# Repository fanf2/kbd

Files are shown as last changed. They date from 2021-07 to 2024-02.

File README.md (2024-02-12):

Tony Finch's keyboard projects
==============================

This repository is where I keep my work on custom mechanical
keyboards.

[HHKBeeb](./hhkbeeb/)
---------

The first keyboard I built is a tribute to the BBC Micro made in the
run-up to its 40th anniversary in 2021.

It uses a [Yiancar HS60](https://yiancar-designs.com/portfolio/337/)
PCB and a generic HHKB case, and keycaps designed by me and printed by
WASD.

The project directory [hhkbeeb](./hhkbeeb/) also contains designs for
an acrylic sandwich case that I never made.

> The default branch in this repository is jokingly called `model-b`
> because git's default branch used to be `master`, and both are kinds
> of BBC Micro.

[Keybird69](./keybird69/)
-----------

In 2023 I designed a 65% keyboard with a "unix69" layout. It uses a
Waveshare RP2040-Tiny controller on a PCB designed by me. The case is
a sandwich of FR-4 and LEGO.

I have assembled three versions of Keybird69:

 1. with Cherry MX Clear switches and Signature Plastics DSS
    "Dolch" keycaps

 2. Cherry MX Clear switches again but with the springs
    lubericated to eliminate their pinging; and with
    [matt3o](https://matt3o.com)'s GMK MTNU Susu keycaps.

 3. Gateron CAP milky brown switches with JTK HSA Hyperfuse keycaps

[Keybird42](./keybird42/)
-----------

My late 2023 / early 2024 work in progress is series of 77% boards:

  - bigger than 75%
  - fewer keys than 80%
  - more symmetrical

They are called keybird42:

  * 42 cm wide PCB
  * 21 keys wide (42 / 2)
  * 84 keys total (42 * 2)

The first version will have a layered acrylic case; there may be others.

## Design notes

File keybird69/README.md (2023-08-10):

Keybird69
=========

This subdirectory contains the notes and designs for Keybird69,
a 65% (69 key) keyboard with a [unix69][] layout and a case made from
FR-4 and LEGO.

[unix69]: https://dotat.at/@/2023-08-04-unix69.html

For blog posts about this keyboard, see

  * <https://dotat.at/@/2023-08-04-keybird.html>

And the followup posts that go into some of the details.

The firmware can be found at:

  * https://github.com/fanf2/qmk_firmware/tree/fanf/keyboards/handwired/fanf/keybird69

Here you can find:

  * `Cargo.toml`
  * `src`
      * some Rust code for generating parts of the QMK configuration,
        and for cross-checking the key matrix design

  * `lego.md`
  * `pcba.md`
      * notes and calculations for the case dimensions

  * `keycaps.md`
      * window-shopping for keycaps for a [unix69][] layout

  * `kicad`
      * schematic and layout for the PCB

  * `ltbs-base`
  * `ltbs-top`
      * kicad designs for the base plate and key switch mounting plate

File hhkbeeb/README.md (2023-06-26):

A keyboard like the BBC Micro, made from modern parts
=====================================================

It's the 40th anniversary of the BBC Micro later this year. I am
trying to make a keyboard in a similar style, made from modern parts.

The Beeb's keyboard was what is now called a mechanical keyboard.
There's a very lively community of mechanical keyboard makers and
customizers, who have made it fairly easy to get a long way with
off-the-shelf parts.

If you would like to make a similar keyboard, please feel free to use
this work as you wish - see the [LICENSE](LICENSE.md) for details.

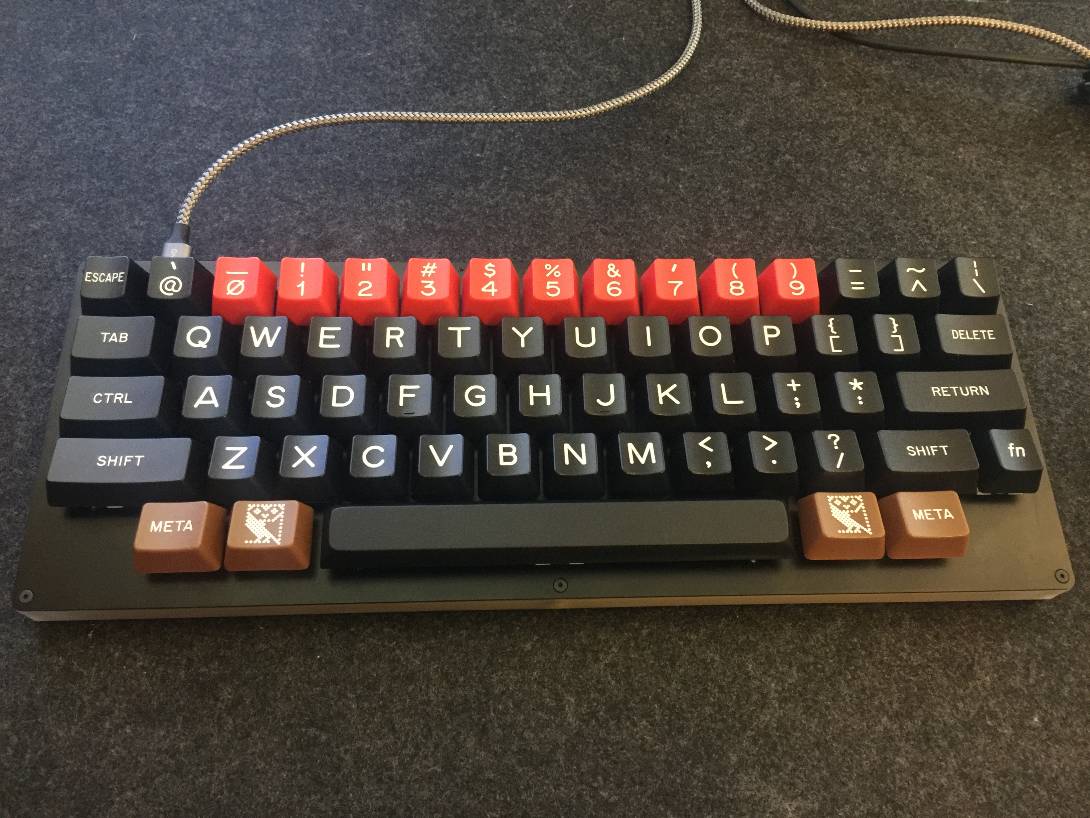
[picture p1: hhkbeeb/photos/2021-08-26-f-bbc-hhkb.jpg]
Happy BBC Micro Hacking keyboard


Contents
--------

  * [The BBC Micro keyboard](#the-bbc-micro-keyboard)
  * [Modern keyboard sizes](#modern-keyboard-sizes)
  * [Adjusting the BBC Micro layout](#adjusting-the-bbc-micro-layout)
      * [ANSI vs ECMA](#ansi-vs-ecma)
  * [Keycaps](#keycaps)
      * [keycap profile](#keycap-profile)
  * [Owl logo](#owl-logo)
  * [WASD keyboard layout](#wasd-keyboard-layout)
  * [Gorton-like fonts](#gorton-like-fonts)
      * [typographical notes on legends](#typographical-notes-on-legends)
      * [legend sizes](#legend-sizes)
  * [Sandwich case](#sandwich-case)
      * [Surround](#surround)
      * [Layers](#layers)
      * [Plate](#plate)
      * [PCB and components](#pcb-and-components)
      * [Fasteners](#fasteners)
      * [Illumination](#illumination)

The BBC Micro keyboard
----------------------

The Beeb's keyboard was mostly a standard [ECMA-23][] layout. The main
oddity from today's point of view is that it has a [bit-paired][]
punctuation layout.

In addition to the basic ECMA-23 keys (all black) the Beeb has some
colourful extras: red function keys and greenish brown arrow keys.

[ECMA-23]: https://en.wikipedia.org/wiki/ECMA-23
[bit-paired]: https://en.wikipedia.org/wiki/Bit-paired_keyboard

I have drawn the [BBC Model B][] and [BBC Master][] keyboard using the
online [Keyboard Layout Editor][KLE] (KLE). The Model B has 74 keys,
and the Master has 93 keys.

[KLE]: http://www.keyboard-layout-editor.com/

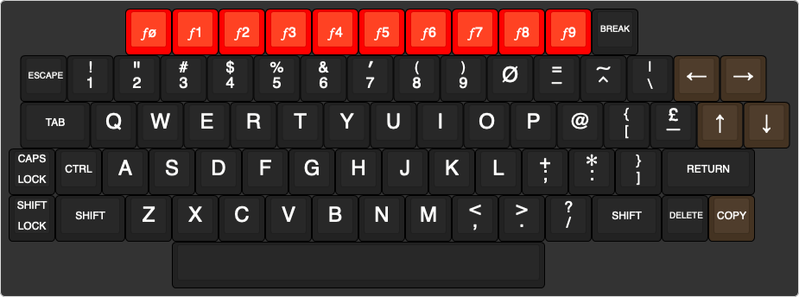
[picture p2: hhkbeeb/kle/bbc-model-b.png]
BBC Micro keyboard layout


Modern keyboard sizes
---------------------

Key sizes are usually quoted as so many "u", as in units, which are
the size of one standard key. 1u is 0.75 inches (19.05 mm).

There are a number of common form-factors, including:

  * Tenkeyless, aka TKL: Like a full-size keyboard without the number
    pad (which has more than 10 keys, shrug)

  * 60%: Just the main block of the keyboard; no function keys or
    arrow keys etc. The overall size is 15u x 5u, typically with 61
    keys.

  * 75%: Like a TKL but with the function and arrow keys smooshed
    together, so there's a single block of keys. The overall size is
    16u x 6u, typically with 84 keys.

The more we re-use one of these standard layouts, the easier it will
be to build (e.g. using off-the-shelf cases and PCBs) at the cost of
authenticity.

Adjusting the BBC Micro layout
------------------------------

The Model B keyboard is slightly wider than a 75% board: CAPS LOCK and
SHIFT LOCK stick out 0.25u on the left, and DOWN sticks out 0.5u on
the right. It can be made to fit in a 75% case by using a BBC Master
arrow cluster, and by displacing the LOCK keys. To be usable with a
modern operating system, the keyboard also needs a few more modifier
keys.

My [BBC Master 75%][] layout is based on those ideas. However, fitting
in the 75% form factor isn't as useful as it might be: in typical 75%
case designs, there are PCB mounting holes mid-way between some of the
function keys, which are aligned with the number row below; but the
Beeb's function keys are offset by 0.5u so they clash with the
mounting holes.

A standard 75% ISO board could be given a Beebish appearance with just
some replacement keycaps, like my [Beeb 75% ISO][] layout.

I like small keyboards, so I have made a [Beeb 60% HHKB][] layout.
This has a slightly jokey number row is shifted towards the centre. My
original design had the number keys in 0-9 order, like the BBC Micro
function keys, but the conventional order turned out to be less
troublesome.

I have labelled the modifier keys in [Space Cadet][] style: meta is
sometimes an alias for alt; [super is a common legend][super] for what
the [USB HID][] spec calls the GUI key; and hyper is for programmable
keymap layers.

[BBC Model B]: http://www.keyboard-layout-editor.com/#/gists/f89a6054d6d76e3fe4a5aa9e5e0e5bec
[BBC Master]: http://www.keyboard-layout-editor.com/#/gists/16e4909fcb8b0c31d4b6a63912db6c3b
[BBC Master 75%]: http://www.keyboard-layout-editor.com/#/gists/71a93d79bc55dbffa7b49be7e8e1d381
[Beeb 75% ISO]: http://www.keyboard-layout-editor.com/#/gists/6a842768ef36cce78c7f452732fe69bf
[Beeb 60% HHKB]: http://www.keyboard-layout-editor.com/#/gists/6791130c7705b4a48605ad0ebdb61e1f
[Space Cadet]: https://en.wikipedia.org/wiki/Space-cadet_keyboard
[super]: https://pimpmykeyboard.com/dsa-black-white-keyset-two-shot/
[USB HID]: https://wiki.osdev.org/USB_Human_Interface_Devices

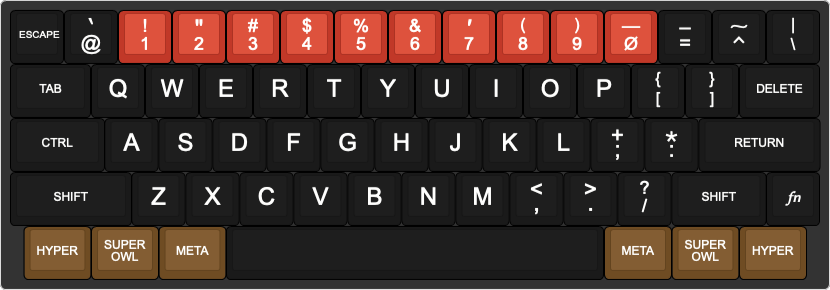
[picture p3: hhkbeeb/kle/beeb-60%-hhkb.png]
Beeb HHKB layout


### ANSI vs ECMA

Unlike AT-101 scan codes, the [USB HID usage table][] for keyboards is
in a layout-independent order (for instance, the letters are
alphabetical), though footnote 2 on USB HID usage page `0x07` says
that language-dependent remapping is handled by the OS (for example,
numbers are shifted on French keyboards, and punctuation is
unshifted). So in practice a USB keycode still corresponds to a key in
a particular position in a conventional keyboard layout.

These keys needed remapping in the OS, with [Ukelele][]:

  * `;+` / `;:`
  * `:*` / `′"`
  * `=-` / `-_`
  * `^~` / `=+`
  * `@‵` / `‵~`

  * `2"` / `2@`
  * `6&` / `6^`
  * `7′` / `7&`
  * `8(` / `8*`
  * `9)` / `9(`
  * `0_` / `0)`

The centred red number keys are remapped in the keyboard firmware with
[VIA][]. This makes the keyboard easier to use when plugged into a
system without further configuration, since most of the keys match the
keycodes suggested by their keycaps.

A disadvantage of remapping using the keyboard firmware is that
software keyboard views in [Ukelele][] and the macOS Keyboard Viewer
do not match the hardware so well. For my layout the main consequence
is that the top row is shifted right one key to make room for ESCAPE,
a small difference that is easy to cope with. (This is one of the
reasons for not keeping the jokey 0-9 number key order.)

[Karabiner Elements]: https://karabiner-elements.pqrs.org/
[Ukelele]: https://software.sil.org/ukelele/
[USB HID usage table]: https://www.usb.org/hid
[VIA]: https://caniusevia.com/

### Configuration details

Mac OS controls: change ⌘` to ⌘@ in System Preferences.

On the keybow, configured with CircuitPy:

   * row 0: F13 - F16
   * row 1: F17 - F20
   * row 2+3: arrows + navigation

Actions on the Keybow configured elsewhere:

  * F13 - F16: mission control / spaces (System Preferences)
  * F17 - F20: tiled window movement (Hammerspoon)
  * alt + F13 - F20: tiled window movement (Hammerspoon)

By default in macOS, modifier keys on one keyboard (e.g. the HS60) do
not affect key presses on another keyboard (e.g. the Keybow). To fix
this, install [Karabiner Elements][]. I don't actually need Karabiner for
anything else...

Keycaps
-------

Most current keyboard layouts are not ECMA-23 (the main exceptions are
Japanese keyboards), so as well as remapping in software, a Beebish
keyboard needs several custom keycaps. This is difficult. The
manufacturing options are, basically:

  * double-shot injection moulding, which would need custom metal
    legends to be fabricated;

  * dye sublimation printing, which is a skilled manual process (so
	one-off keycaps can cost $5 each), and cannot normally do
	white-on-black;

  * pad printing; laser etching; neither of which appear to be a
    popular option for custom keysets;

  * UV cured, used by print-on-demand suppliers.

Double-shot and dye-sub sets give you a lot of choice in [keycap
profile][] and type of plastic, but have a large minimum order
quantity. Custom set manufacturing is usually organized with a "group
buy" process, like a DIY kickstarter.

Custom UV printed keyboards are available from [Max Keyboard][] and
[WASD Keyboards][]; both of them will only print on to ABS plastic
with the OEM profile.

### keycap profile

The BBC Micro keycap profile is uniform (all rows the same, not
sculptured like the [OEM profile][]) with shallow spherical keytops
(not cylindrical like OEM), and all keytops angled backwards (not flat
like the [DSA profile][SP families]) to produce a stairstep effect
when the whole board is angled forwards.

It was probably the [Comptec / Signature Plastics][SP origins] old SA
profile, before SA was changed from uniform to sculptured. A modern
version might be to use [SA or DSS][SP families] (both are spherical
and sculptured) but made into a uniform set by manufacturing all keys
with a shape from the same row.

[beeb keycap closeups]: https://geekhack.org/index.php?topic=28630.0
[keycap profile]: https://old.reddit.com/r/MechanicalKeyboards/comments/j484j5/keycap_profiles_i_compiled_a_direct_comparison/
[Max Keyboard]: https://www.maxkeyboard.com/shop/cherry-mx-keycaps/custom-color-printed-keycaps/
[OEM profile]: https://support.wasdkeyboards.com/hc/en-us/articles/115009701328-Keycap-Size-Compatibility
[SP families]: https://pimpmykeyboard.com/key-cap-family-specs/
[SP origins]: https://pimpmykeyboard.zendesk.com/hc/en-us/articles/204415935-The-Origin-of-SP-Keycap-Families
[WASD Keyboards]: https://www.wasdkeyboards.com/products/keycaps/keycap-set.html

Owl logo
--------

The BBC Micro was part of the BBC's computer literacy project, whose
logo was a dot-matrix owl. I have previously made my own version of
[the BBC owl in SVG](http://dotat.at/random/bbc-owl.html), which I am
going to re-use as an [owl keycap legend](owl/bbc-owl.svg). I have
removed the blobby effect from the keycap version, because printing
will take care of that for me.

The owl will appear on the GUI / OS / Win / command keys, so it will
be a super beeb owl.

owl logo

WASD keyboard layout
--------------------

I have turned [my KLE HHKB design][Beeb 60% HHKB] into a layout for
submission to WASD for manufacturing. The [beeb.svg](wasd/beeb.svg)
file has the keycap legends as text for editing; the
[paths.svg](wasd/paths.svg) file has legends as paths for printing.

This layout has the number row in a more common order, to reduce the
risk of misunderstandings by the WASD staff. I edited the [WASD
template][] so that it has a split backspace and split right shift, to
match the HHKB layout, and I made the background black for better
contrast with the white legends.

[WASD template]: https://support.wasdkeyboards.com/hc/en-us/articles/115007847008-Download-Template-Files

The modifiers on the bottom row do not match the HHKB exactly. The
original HHKB has a 6u spacebar with two modifiers either side. I have
an [HS60 HHKB PCB][HS60] which has a [Tsangan][] bottom row: a 7u
spacebar with three modifiers (1.5u, 1u, 1.5u) each side; WASD do not
have a 7u spacebar or 1.5u row 1 modifiers.

I'm going to get a 7u spacebar elsewhere; the 3 x 1.25u modifier keys
from WASD will fit the Tsangan layout, except for a 0.125u gap on each
side (i.e. 1/8 * 3/4 inch or 2.4mm) which I think is tolerable.

I would probably prefer ctrl/delete/return/shift/tab to be brown, but
WASD do not have brown 1.75u shift keys, so it's better to leave them
all black.

Colour matching is somewhat problematic. WASD brown (#6F4C23) is the
closest to the BBC Micro arrow keys (RAL 8014, #4A3526). The function
key colour (RAL 2005 #FF4d06 or RAL 2009 #de5307) is somewhere between
WASD red (#C9282D) and orange (#F67F00).

[HS60]: https://mechboards.co.uk/shop/parts/hs60-hotswap-pcb/
[Tsangan]: https://old.reddit.com/r/MechanicalKeyboards/comments/euvl59/eli5_tsangan_layout_etymology_origins_and/

WASD design file

Gorton-like fonts
-----------------

The BBC Micro keycaps were made by Comptec, who are now known as
[Signature Plastics][]. Their main style of legends is called "Gorton
Modified", named after [Gorton engraving machines][Gorton Machine].

[Signature Plastics]: https://pimpmykeyboard.com/
[Gorton Machine]: http://gorton-machine.org/

There are a number of fonts made in the style of engraving machine
lettering.

The best I have found so far is [Routed Gothic][], which has a large
repertoir of characters, though some of them are not good matches for
Gorton Modified.

[Open Gorton][] has better matches for some character shapes; it
covers ASCII only, and its weights are a bit inconsistent.

There is another font called [Gorton Digital][], which is available as a
FontForge script not as built font files. Unfortunately the script
produced mangled output when I tried it, though some of the characters
are usable.

Also worth noting are [National Park][] (whose repertoir is roughly
ISO 8859-1); [DSKY Gorton Normal][] which aims to match the
lettering on the Apollo display and keyboard (it has just uppercase
and digits); [Quarkwell][], which is a recently created commercial Gorton-alike

[DSKY Gorton Normal]: https://github.com/ehdorrii/dsky-fonts
[Gorton Digital]: https://github.com/drdnar/GortonDigital
[National Park]: https://nationalparktypeface.com/
[Open Gorton]:  https://github.com/dakotafelder/open-gorton
[Quarkwell]: https://www.myfonts.com/fonts/thetypeworks-com/quarkwell/
[Routed Gothic]: https://webonastick.com/fonts/routed-gothic/

What I found worked best for the WASD design was a combination of
Routed Gothic, Routed Gothic Wide, and Open Gorton.

### typographical notes on legends

These notes refer to the [beeb.svg](wasd/beeb.svg) WASD design file.

CTRL, SHIFT, etc. are all Routed Gothic, except for ESCAPE and DELETE
which are Routed Gothic Narrow, and `fn` is Routed Gothic Italic.

Most of the letters and digits are Routed Gothic Wide. A few letters
are Routed Gothic (non-wide): `R` `S` `P` `B`

`J` is problematic: Open Gorton has a more authentically wide glyph
shape, but its weights don't match Routed Gothic (regular is too
light; bold is too heavy). To fix this, I converted the Open Gorton
`J` to a path and gave it a wide stroke to embolden it to match the
other letters.

Zero is a Scandinavian capital slashed O and the correct 1 is found in
Routed Gothic's private use character codes.

`3` is problematic. Again, Open Gorton has a more authentic shape
(rounded top instead of angular), but its numerals are too narrow. I
stuck with Routed Gothic Wide.

For punctuation, `#$%&^~,.;:<>` come from Open Gorton; `"(){}[]`
from Routed Gothic Wide, and `+-=‵′/|\?!` from Routed Gothic.

The Routed Gothic `@` is too bold, but the Open Gorton version looks
like it has been melted a bit. I traced an `@` from Quarkwell and
emboldened it using the same trick as for `J`.

For symmetry I used reversed prime and prime for `‵′` and rotated them
slightly to make them more distinct. `|` is a Beebish broken bar, `_`
is drawn using an em-dash, and `-` uses an en-dash.

I upped the font size a lot for `,.;:^~*`

Asterisk is tricky. The `*` on the BBC micro has 6 points; Open Gorton
has 8 points, a bit like the `*` on the BBC Master's numeric keypad
(though I think Open Gorton has shorter points). Current Gorton
Modified keycaps seem to use an 8-point asterisk. But in the end I
chose the nice 5-point asterisk from Gorton Digital.

### legend sizes

The legends on the BBC Micro keycaps are centred; the two-story
legends occupy almost all of the vertical space on the keycaps.
Measurements are roughly:

  * letters, arrows: 0.5 keytop height

  * modifiers, actions: 0.25 keytop height

  * digits, punctuation, function keys: 3/8 keytop height

On the WASD templates, the keycaps are 1/2 in by 5/9 in.

After some advice from WASD's support staff, I left about 5% gap
between the legends and the keycap edges to avoid printing problems.
The Beeb number keys look like they were a bit closer than that.

Sandwich case
-------------

A fairly common and straightforward way to make a custom keyboard case
is with sandwiched acrylic, like the [Pibow][]. There's even an online
[plate and case builder][] that takes [KLE][] JSON and produces CAD
files for laser cutters.

I am not yet sure what will work best. I have a couple of possible
designs which are compared in [sandwich.svg](case/sandwich.svg). I am
going to try them out using a [Keybow 2040][], which in some ways is a
miniaturized [HS60][].

Sandwich case draft designs

[Pibow]: https://www.raspberrypi.org/blog/pibow/
[plate and case builder]: http://builder.swillkb.com/
[Keybow 2040]: https://learn.pimoroni.com/tutorial/hel/assembling-keybow-2040

### Surround

From measuring [Wikipedia's picture of a BBC Micro][BBC Micro photo],
the sizes of the top of the case around the keys are round multiples
of a key unit.

  * right of arrows: 0.5u black, 1.0u cream

  * left of lock keys: 2.0u black, 1.0u cream (expansion socket)

  * below space: 0.5u black, 0.75u cream

  * function key strip holder: 1.5u

  * overall width (from Acorn's manual): 415mm = 21.75u

  * calculated width: 16.75u (keys) + 1.5u (right) + 3u (left) = 21.25u

(It isn't clear where the 0.5u discrepancy comes from...)

The [Acorn Atom][] had a similar design for the keyboard surround. Its
dimensions were less clearly multiples of a key size, roughly:

  * right of break: 1.5u black, 1.0u cream (speaker)

  * left of arrows: 0.5u black, 1.0u cream

  * below space: 0.25u black, 0.5u cream

  * above numbers: 0.75u black

The [Acorn Electron][] lacked the black part of the keyboard surround:
instead, the corresponding part of the case was textured beige, and
the sides were smooth.

  * sides: 1/3u textured, 1u smooth

  * below space: 0.75u textured (no smooth part)

  * above numbers: 0.125u textured, 1.5u green grid with logo

My case design has:

  * sides: 1u black, 1u cream (like the Beeb and Atom, but centred)

  * below space: 0.5u black, 0.75u cream (like the Beeb)

  * above numbers: 0.5u black, 1.25u cream (for a whole number of units)

  * overall width: 19u

[BBC Micro photo]: https://en.wikipedia.org/wiki/File:BBC_Micro_Front_Restored.jpg
[Acorn Atom]: https://en.wikipedia.org/wiki/File:Acorn_atom_zx1.jpg
[Acorn Electron]: https://en.wikipedia.org/wiki/File:Acorn_Electron_4x3.jpg

### Layers

The constraints on the height of the keyboard come from:

  * the keyswitches;
  * the PCB;
  * the controller components.

The layers above the PCB are determined by the keyswitches, as
documented in a [Cherry MX data sheet][].

### Plate

The most important layer is the plate, which ensures that the keys are
straight and correctly spaced. It also contributes a lot to the feel
and sound of the keyboard. The top of the plate must be 5mm above the
PCB. For the keys to clip in properly, the plate must be 1.5mm thick.

Acrylic is problematic for keyboard plates, because thin sheets can be
too brittle, and they have fewer choices of colour than thicker
sheets. So some designs use a 5mm acrylic plate, into which the keys
fit by friction instead of being clipped in.

A "high profile" case has a surround above the plate which hides the
keyswitches. The [Cherry MX data sheet][] suggests that the surround
should be something like 4.5mm or 6mm above the plate to match the
bottom of the keycaps. Keycaps are about 8mm high (depending on their
profile) and have 4mm travel.

### PCB and components

Apart from the switches, the keyboard electronics are below the PCB,
which itself is about 1.5mm thick.

To save on soldering, I'm using hot-swap PCBs; the [Kailh socket data
sheet][] says these are 2mm thick. The HS60 also has a discrete
component that's 2.5mm thick, and the Keybow has a couple of reset
buttons that are about 4mm thick.

According to the [USB-C connector specification][], the socket is
about 3.5mm thick x 8.5mm wide.

USB plugs need further clearance: they are up to 6.5mm x 12.5mm.

Plug clearance above the PCB: 3.5mm/2 - 6.5mm/2 = -1.5mm, same as the
thickness of the PCB.

Below the PCB: 3.5mm/2 + 6.5mm/2 = 5mm.

The plug only needs space in the case surround so it does not
necessarily need to clear the bottom cover: it can plug into a recess.
This means the bottom of the keyboard as a whole is set by the USB
plug.

In my design that uses 5mm sheets for the outer sandwich, there might
not be enough clearance above the USB socket or Keybow reset buttons,
so the recess may need to be larger.

[Cherry MX data sheet]: https://raw.githubusercontent.com/keyboardio/keyswitch_documentation/master/datasheets/Cherry/mx_series.pdf

[Kailh socket data sheet]: https://raw.githubusercontent.com/keyboardio/keyswitch_documentation/master/datasheets/Kailh/CPG151101S11_MX_Socket.pdf

[USB-C connector specification]: https://www.usb.org/document-library/usb-type-cr-cable-and-connector-specification-revision-21

laser cut outlines for case

### Fasteners

I would like to avoid sticking-out nuts and screw heads. (The Pibow
uses M2.5 nylon screws which stick out about 2mm.) Unfortunately, it's
not a good idea to use countersunk heads with acrylic because
tightening the screws can cause cracking.

One possibility is to use M2 or M2.5 female-female standoffs inside
the case sandwich, so that only screw heads protrude on the top and
bottom; then choose the flattest heads available.

There is more variety of fasteners in M3 sizes. I'm going to try using
[rivet nuts][] on the bottom because they only protrude 0.8mm. Rivet
nuts are designed to be inserted into a metal panel; a riveting tool
is inserted into the nut to squash it so that it wedges in the panel.
But I don't need this rivet action, just the flange and the internal
thread.

[rivet nuts]: https://en.wikipedia.org/wiki/Rivet_nut

On the top, I will use black screws that go through the recessed black
keyboard surround, so they should be fairly unobtrusive. The most low
profile screw heads I have found are described as "ultra thin super
flat wafer head".

To fix the outer cream surround (where I want to avoid visible screw
heads) I will try acrylic cement, or superglue, or silicone sealant. I
believe silicone sealant can be removed with a knife and re-done, and
it can fill gaps if the fit of the acrylic isn't perfect, so it should
be more forgiving.

Rivet nut dimensions:

  * diameter of flange: 7mm
  * diameter of barrel: 4.9mm
  * overall length: 9mm
  * depth of flange: 0.8mm

M3 wafer head screw dimensions:

  * diameter of hole: 3.1mm
  * diameter of head: 5.8mm - 6.1mm
  * depth of head: 0.9mm - 1.0mm

### Illumination

No keyboard is properly blinged up without RGB LEDs.

It so happens that thin sheets of acrylic are only available as
transparent, so the bottom cover naturally allows an underglow effect.

My 3mm sandwich sketch has a 1.5mm transparent keyswitch plate that
extends out to the edge of the keyboard to make a go-faster stripe.

For the black key surround I would actually like to use dark grey
tinted acrylic, so RGB backlights can shine through a little.

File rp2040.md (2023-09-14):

rp2040 pcb design
=================

examples:

  * pro micro style
      * https://github.com/0xCB-dev/0xCB-Helios
      * https://github.com/joshajohnson/sea-picro
      * https://github.com/piit79/Frood
      * https://github.com/plut0nium/0xB2/
  * complete keyboard
      * https://github.com/jpconstantineau/pykey60

guides - rp2040:

  * https://www.raspberrypi.com/documentation/microcontrollers/rp2040.html
  * https://datasheets.raspberrypi.com/rp2040/hardware-design-with-rp2040.pdf
  * https://www.digikey.com/en/maker/projects/hardware-design-with-the-rp2040-part-2-pcb-layout/850cdf59974a4de3b749f94aa318c1f5
  * https://pcbartists.com/design/embedded/rp2040-pcb-design/
  * https://github.com/Sleepdealr/RP2040-designguide
  * https://www.teachmemicro.com/designing-a-pcb-for-the-rp2040-microcontroller/

guides - keyboard:

  * https://wiki.ai03.com/books/pcb-design
  * https://github.com/ruiqimao/keyboard-pcb-guide

BOM
---

Aiming to use JLCPCB "basic" parts as much as possible,
and avoid "standard only" (which rules out kailh sockets).

  * flash 16 MB
      - https://jlcpcb.com/partdetail/C97521
      - SOIC-8-208mil (7.9 / 5.2 x 5.2 x 2.0 mm)
      - $0.5842

  * power
      - https://jlcpcb.com/partdetail/C6186
      - SOT-223-3 (7.0 / 3.5 x 6.5 x 1.8 mm)
      - $0.1312

  * xtal 12 MHz
      - https://jlcpcb.com/partdetail/C9002
      - SMD3225-4P (3.2 x 2.5 x 0.7 mm)
      - $0.0550
      - load capacitance 20pf
      - 2 x 33pF 0402 C1562
      - 1 x 1kΩ 0402 C11702

extended parts:

  * rp2040
      - https://jlcpcb.com/partdetail/C2040
      - LQFN-56 (7.0 x 7.0x 0.9 mm)
      - $0.9761

  * usb-c "sink board" 16 pin
      - https://jlcpcb.com/partdetail/C2936201
      - 6.5 x 11.7 x -1.6+1.6 mm
      - $0.1792

alternative extended parts:

  * flash 2 MB
      - used on the pico
      - https://jlcpcb.com/partdetail/C2843335
      - USON-8-EP (2.0 x 3.0 x 0.6 mm)
      - $0.5871

  * xtal 12 MHz
      - https://jlcpcb.com/partdetail/C255987
      - SMD1612-4P (1.6 x 1.2 x 0.4 mm)
      - $0.2455

  * power
      - used on the seeed xiao
      - https://jlcpcb.com/partdetail/C379347
      - XDFN-4-EP (1.0 x 1.0 x 0.4 mm)
      - $0.0652

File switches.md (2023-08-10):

notes on keyswitches
====================

Generalally I prefer tactile keys, because they indicate the actuation
point without making a lot of noise (like clicky keys). Linear keys
have advantages for gaming when you want to oscillate around the
actuation point.

Cherry MX Clear
---------------

I like [Cherry MX Clear](https://www.cherrymx.de/en/cherry-mx/mx-special/mx-clear.html)
because the spring force increases a lot after the actuation point, so
it's relatively easy to type on them without bottoming out. This makes
them a bit like a short-travel keyboard that botttoms out really
softly.

The force curve for many tactile switches has about the same force
for the tactile point and for bottoming out, so there are fewer cues
for the typist about the vertical position of their fingers.

alternatives?
-------------

I think I would like a similar force curve to the clears -- the spring
force after actuation is larger than the tactile force, and the
tactile bump is very distinct -- but with a lower actuaton force and
shorter travel to actuation.

  * https://drop.com/buy/drop-halo-switch-pack
      * seem to have a similar force curve to clears

modifiers
---------

Modifier keys are an exception to my general preference for tactile keys.

I'm currently using [Cherry MX Silent Black](https://www.cherrymx.de/en/cherry-mx/mx-original/mx-silent-black.html)
as a rough match for the force of Clears without the tactile bump.
This is a new-ish experiment; matching the force was kind of a guess.

It's worth considering [Cherry MX Speed Silver](https://www.cherrymx.de/en/cherry-mx/mx-original/mx-speed-silver.html)
as an alternative, based on the observation that modifiers are often
pressed by the little finger, so a lighter spring might make sense.

bottom row
----------

I am still experimenting with my space bar.

I currently have a [Cherry MX Grey](https://www.cherrymx.de/en/cherry-mx/mx-special/mx-grey.html)
switch, because it is apparently common to have a harder switch in the
space bar compared to the rest of the keyboard. (So, for example,
black is the space switch for a mostly-red keyboard, green is the
space switch for a mostly-blue keyboard.)

The grey bottom-out force is about the same as in a clear switch,
100g, though the tactile force is 80g instead of 60g.

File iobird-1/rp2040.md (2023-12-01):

rp2040 pcb design
=================

examples:

  * pro micro style
      * https://github.com/0xCB-dev/0xCB-Helios
      * https://github.com/joshajohnson/sea-picro
      * https://github.com/piit79/Frood
      * https://github.com/plut0nium/0xB2/
  * complete keyboard
      * https://github.com/jpconstantineau/pykey60

guides - rp2040:

  * https://www.raspberrypi.com/documentation/microcontrollers/rp2040.html
  * https://datasheets.raspberrypi.com/rp2040/hardware-design-with-rp2040.pdf
  * https://www.digikey.com/en/maker/projects/hardware-design-with-the-rp2040-part-2-pcb-layout/850cdf59974a4de3b749f94aa318c1f5
  * https://pcbartists.com/design/embedded/rp2040-pcb-design/
  * https://github.com/Sleepdealr/RP2040-designguide
  * https://www.teachmemicro.com/designing-a-pcb-for-the-rp2040-microcontroller/

guides - keyboard:

  * https://wiki.ai03.com/books/pcb-design
  * https://github.com/ruiqimao/keyboard-pcb-guide

BOM
---

Aiming to use JLCPCB "basic" parts as much as possible,
and avoid "standard only" (which rules out kailh sockets).

  * flash 16 MB
      - W25Q128JVSIQ
      - https://jlcpcb.com/partdetail/C97521
      - SOIC-8-208mil (7.9 / 5.2 x 5.2 x 2.0 mm)
      - $0.5842

  * power
      - https://jlcpcb.com/partdetail/C6186
      - SOT-223-3 (7.0 / 3.5 x 6.5 x 1.8 mm)
      - $0.1312

  * xtal 12 MHz
      - https://jlcpcb.com/partdetail/C9002
      - SMD3225-4P (3.2 x 2.5 x 0.7 mm)
      - $0.0550
      - load capacitance 20pf
      - 2 x 33pF 0402 C1562
      - 1 x 1kΩ 0402 C11702

extended parts:

  * rp2040
      - https://jlcpcb.com/partdetail/C2040
      - LQFN-56 (7.0 x 7.0x 0.9 mm)
      - $0.9761

  * usb-c "sink board" 16 pin
      - https://jlcpcb.com/partdetail/C2936201
      - 6.5 x 11.7 x -1.6+1.6 mm
      - $0.1792

alternative extended parts:

  * flash 2 MB
      - W25Q16JVUXIQ
      - used on the pico
      - https://jlcpcb.com/partdetail/C2843335
      - USON-8-EP (2.0 x 3.0 x 0.6 mm)
      - $0.5871

  * xtal 12 MHz
      - https://jlcpcb.com/partdetail/C90603
      - SMD2520-4P (2.5 x 2.0 x 0.55 mm)
      - $0.2261
      - load capacitance 6 pF
      - 2 x 12 pF

  * power
      - used on the seeed xiao
      - https://jlcpcb.com/partdetail/C379347
      - XDFN-4-EP (1.0 x 1.0 x 0.4 mm)
      - $0.0652

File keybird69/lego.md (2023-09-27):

lego technic beam sandwich
==========================

Originally inspired by James Munns, who [uses Lego for mounting
PCBs][bitshiftmask1], including [at least one keyboard][bitshiftmask2].

[bitshiftmask1]: https://twitter.com/bitshiftmask/status/1590395981686001664
[bitshiftmask2]: https://twitter.com/bitshiftmask/status/1376170525224022018

The first idea was to make a keyswitch plate from FR4 (i.e. a PCB with
appropriate cutouts) mounted on Lego bricks which form the enclosure,
somewhat like https://kbdcraft.store/products/adam

This was too difficult to make slender, largely because the distance
from the switch plate to the studs is about 8mm, less than the 5mm +
3.5mm needed for the switches and USB socket. But an FR4 base plate is
more adaptable with the possibility of cutouts, so I changed to a
sandwich design instead.

I failed to make the case for my HHKBeeb because it was toto hard to
find somewhere that could cut acrylic to my spec. Lego technic beams
are easier to obtain, albeit less flexible.

So the idea is to make an FR4 sandwich case, with lego technic beams
enclosing the sides between the switch plate and base plate.

lego dimensions
---------------

  * 1x1 brick is 8x8 mm (same as my HHKBeeb's surround)

  * plate height 3.2 mm
  * brick height 9.6 mm
  * stud height 1.7 mm
  * stud diameter 4.8 mm

  * clip diameter 3.2 mm (same as holes in studs)
      - might be useful with M3 bolts

  * technic hole diameter 4.8 mm
  * technic beam height 8 mm (along length of holes)
  * technic beam width 7.2 mm (diameter of end curve)

fasteners
---------

Two options:

  * M3 rivet nuts and bolts. 5mm outer diameter of rivet nut will
    press fit very firmly into a technic hole. I will use this
    since I have the bits left over from HHTBeeb.

  * M2 standoffs and bolts. M2 hex nut face-to-face distance is 4mm,
    corner-to-corner is 4.5mm, easily fits into technic hole. Needs to
    rely on friction against the plates to hold the beam in place.

nominal board dimensions
------------------------

16 keys * 19.05 mm = 304.8 mm

5 keys * 19.05 mm = 95.25 mm

38.1 x 11.9 studs => 3 x 13m beam wide, 1 x 13m beam deep

PCB dimension tolerance 0.2 mm

### component clearance

  - 5 mm switches + pcb
  - 1.9 mm hotswap socket
  - 2.1 mm RP2040-Tiny

  - max 7.1 mm

  - 8 mm technic beam

  - 1 mm clearance under sockets
  - 3 mm clearance under PCB

RP2040-Tiny USB adapter
-----------------------

outer dimensions 18 x 18 mm
  * corner radius 1 mm
  * board 1.6 mm thick

mounting holes
  * diameter 2 mm
  * centre to edge of board 2 mm

### components

based on web site image, 220 px == 18 mm

  * FPC connector
      - 1 mm thick
      - 6.5 mm wide
      - ??? 4.9 mm flex lead

  * buttons
      - 2.5 mm thick

  * USB socket
      - 7.5 mm deep
      - 9 mm wide

  * thickness step from 2.5 mm to 5 mm
      - 12.25 mm to USB edge of board
      - 5.75 mm to FPC edge of board

### limits on position

  * 2.5 mm hotswap to nominal edge

  * adapter on top of base plate
      - FPC connector under PCB
      - 15.5 mm nominal edge to USB edge

  * adaptor flush with base
      - FPC connector under sockets
      - PCB cutout for buttons
      - 9.75 mm nominal edge to USB edge

rectangular enclosure
---------------------

could not make space to mount the USB adapter nicely

angled enclosure
----------------

rectangular round the front, gentle enlargement at the back

front beams

  * whole studs, 38 * 8 = 304 mm
  * narrow gaps, 303.2 mm
  * tight, 302.4 mm

distance between end holes

  * whole stud, 8 mm
  * narrow gap, 7.6 mm
  * tight, 7.2 mm

isoceles corner triangle

  * h = 7.6 mm
  * b = `sqrt( 7.6 * 7.6 / 2 )`
  * b = 5.4 mm

internal distance between side beams

  * 303.2 + 5.4 * 2 - 7.2
  * 306.8 mm
      - 1 mm clearance either side of 304.8 mm nominal

internal distance between front and back beams

  * 12 * 8 + 5.4 * 2 - 7.2
  * 99.6 mm
      - 95.25 mm nominal plus 4.35 mm
      - 0.35 mm clearance at front, 4 mm space at back

angle rear beams so that space from nominal rear to enclosure rear is:

  * 2 mm FPC under PCB
  * 16 mm rest of USB adapter

stabilizer cutouts
------------------

cherry data sheet says

0.94 in between stab keycap mounts = 23.876 mm

0.166 in between mount and outer edge of cutout = 4.216 mm

0.262 in cutout width = 6.65 mm

width between outer edges of cutouts = 32.31 mm

space between switch cutout and stab cutout = 2.515 mm

ai03 uses 7 mm width, centred on keycap mounts

width between outer edges of cutouts = 30.876 mm

space between switch cutout and stab cutout = 1.438 mm

swill uses 6.75 mm cutout width

space between switch cutout and stab cutout = 1.525 mm

width between outer edges of cutouts = 30.55

gateron stab housing is 7 mm x 11.25 mm

dunno how it fits?!

slop between housing and support is large, 1mm

let's use 7 mm stab cutouts,
aligned with and 1.5 mm from the switch cutout

maxkeyboard says spacing between switch centre and stab centre is 12 mm

so 14 / 2 + 1.5 + 7 / 2 = 7 + 1.5 + 3.5 = 12 mm

matt3o uses 19.05 * (2.25 - 1) / 2 = 11.9 mm

vertical size of cutout needs extra clearance for stab wire

cherry has 0.484 - 0.26 = 0.224 in = 5.7 mm above

and below 0.53 - 0.224 = 0.306 in = 7.8 mm below

ai03 has 6 mm above 9 mm below

I think 8+8 should be plenty

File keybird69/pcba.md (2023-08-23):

pcba notes
==========

flexible layout
---------------

### pi60 HSE

staggered hotswap sockets support both ANSI and Tsangan

incompatible with per-key RGB LEDs where alternative key positions
have sockets above and below

https://1upkeyboards.com/shop/controllers/1upkeyboards-pi60hse-60-pcb/

### planck hot-swap

another example of staggered sockets

https://drop.com/buy/planck-mechanical-keyboard

reduced height
--------------

  * 1.5 mm plate
  * 3.5 mm switch bodies
  * 1.5 mm pcb
  * 2.0 mm hotswap sockets
  * 1.5 mm base

total 10 mm

USB-C dimensions

  * 1.5 mm plug clearance
  * 3.5 mm USB-C socket
  * 1.5 mm PCB / plug clearance

mid-mount USB-C socket is flush with one surface of PCB

  * 1.5 mm plug clearance
  * 2.0 mm socket
  * 1.5 mm PCB / socket
  * 1.5 mm plug clearance

mid-mount socket might fit in the usual place between esc and 1 ?
or centred between 7 and 8 ?

(won't be compatible with standard cases)

USB plug positions:

(first two need a PCB extension)

  * top mount
      - 0.0 mm above
      - 1.5 mm plate / plug clearance
      - 3.5 mm switch bodies / socket
      - 1.5 mm pcb / plug clearance
      - 2.0 mm components / below
      - 1.5 mm base / below

  * upper mid-mount
      - 1.5 mm plate / above
      - 1.5 mm switch bodies / plug clearance
      - 2.0 mm switch bodies / socket
      - 1.5 mm pcb / socket
      - 1.5 mm components / plug clearance
      - 0.5 mm components / below
      - 1.5 mm base / below

  * lower mid-mount
      - 1.5 mm plate / above
      - 2.0 mm switch bodies / above
      - 1.5 mm switch bodies / plug clearance
      - 1.5 mm pcb / socket
      - 2.0 mm components / socket
      - 1.5 mm base / plug clearance
      - 0.0 mm below

  * bottom mount
      - 1.5 mm plate / above
      - 3.5 mm switch bodies / above
      - 1.5 mm pcb / plug clearance
      - 2.0 mm components / socket
      - 1.5 mm base / socket
      - 1.5 mm overhang / plug clearance

### Drop Alt

Upper mid-mount USB-C.

PCB is larger than usual with edge-mounted RGB LEDs
and extra projections for the USB sockets

https://drop.com/buy/drop-alt-pcba

The case is supposed to be 9mm thick; I guess they shaved some space
from the components and used a really thin baseplate

https://drop.com/buy/drop-alt-aluminum-case

### KBDcraft Adam

Top-mount USB-C

Sticks out on a finger of board into high-profile case surround.

https://kbdcraft.store/products/core64

diy controllers
---------------

matrix gpio pins:

  - 16 + 5 -> 21 pins
      * simple matrix needs lots of pins
      * fewest for 69 keys is 17 pins

  - 72 = 9 * 8 -> 17 pins
      * 16 key columns in pairs -> 8 matrix columns
      * max 9 keys per matrix column

### rp2040-tiny

https://www.waveshare.com/rp2040-tiny.htm
https://www.waveshare.com/wiki/RP2040-Tiny

separate controller and usb adaptor boards

controller dimensions 18 x 23.5 mm (same as a 1.25u keycap)

19 gpio pins

  * adaptor mounted on base
      - 1.5 mm plate / above
      - 1.5 mm switch bodies / above
      - 1.5 mm switch bodies / plug clearance
      - 0.5 mm switch bodies / socket
      - 1.5 mm keyboard pcb / socket
      - 1.5 mm socket
      - 1.5 mm adaptor pcb / plug clearance
      - 1.5 mm base / below

buttons behind socket conflict with keyboard pcb

best solution is probably an underplate

  * adaptor mounted on underplate
      - 1.5 mm plate / above
      - 3.5 mm switch bodies / above
      - 1.0 mm keyboard pcb / plug clearance
      - 0.5 mm keyboard pcb / socket
      - 3.0 mm components
      - 1.5 mm adaptor pcb / base / plug clearance
      - 1.5 mm underplate / below

adaptor dimensions 18 x 18 mm (same as a keycap)

mounting holes 2 mm, 1 mm from board edge

socket depth 7.8 mm

button depth 8.5 ... 12.2 mm

button width 1.1 ... 5.5 mm

### elite-pi

https://keeb.io/products/elite-pi-usb-c-pro-micro-replacement-rp2040

mid-mount usb socket

25 gpio pins

### 0xCB helios

https://keeb.supply/products/0xcb-helios

mid-mount usb socket

21 gpio pins

copper
------

how much does copper affect weight?

typically 1 oz / sq. ft.

key matrix N by M

base is roughly (N + 1) * (M + 1) * 0.75 * 0.75 / 12*12 sq. ft.

= (N+1) * (M+1) / 256

plate is base - cutouts

cutouts are roughly N * M * (14 / 12*25.4)^2

= N * M / 480

total is 4 * base - 2 * cutouts

= (N+1) * (M+1) / 64 - N * M / 240

for 65%

= 17 * 6 / 64 - 16 * 5 / 240 = 1.26 oz = 36 g

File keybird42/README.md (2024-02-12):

keybird42
=========

http://www.keyboard-layout-editor.com/#/gists/dae8374b0ce94d88869aaf67bffb43e0

The main niggle about keybird69 is the lack of gap between delete &
return, and the function column. Sculpted keycaps go some way to
mitigating it, but not completely.

I played around with layouts that have a separated arrow cluster and
function columns (like a reduced 1800 layout), but they make it harder
to use the arrow keys with the thumb on a modifier.

So keybird42 has the following features:

  * unix / hhkb / tsangan main block, i.e.
      - split backspace, with backslash and backquote taking its place
      - escape above tab, left of 1
      - control below tab, left of A
      - delete above return
      - 1.75u right shift with fn key to its right

  * modified tsangan bottom row
      - 1.25 1.25 1.5 7 1.5 1.25 1.25
      - better symmetry
      - reasonable space bar compatibility
      - leftmost and rightmost modifiers have equal sizes
          + more keycap options

  * compared to usual 6.25 bottom row, tsangan has
      - left meta key slightly further right
          + better ergonomics for M-x
          + more like apple keyboard
      - right meta key further right
          + easier to reach with fingers on arrow keys

  * modified arrow and nav cluster to the right
      - like tenkeyless board
      - arrow cluster moved 0.5u upwards
          + easier to reach modifiers with thumb
      - nav cluster moved 0.25u downwards
          + better vertical symmetry
          + equal gaps between clusters

  * function keys moved to left
      - function-rowless
      - two clusters of 6 mirroring the nav and arrow clusters
      - vaguely PC AT reto feel, but more symmetry

  * 77%
      - bigger than 75%
      - fewer keys than 80% (aka tenkeyless)
      - more symmetrical

The result is a board with 84 keys and some lovely symmetries,
and better modifier + arrow key ergonomics than usual.

I called it keybird42 because:

  * 42 cm wide PCB
  * 21 keys wide (42 / 2)
  * 84 keys total (42 * 2)
  * 5 keys deep (fnord)
  * 23 key unit wide case (fnord)
  * 6.666 key unit deep case (devilish)

window placement
----------------

I intend to use the left hand function clusters to move windows into
the places I like on my 4K display. The most useful positions for me
are:

   * 4 columns, quarters
   * 3 columns, thirds
   * 3 columns, 1/4 1/2 1/4
   * 2 halves side-by-side
   * 1/3 and 2/3 side-by-side

These fit into the 12 function keys fairly nicely, thus:

        +---+---+---+
        |1  |2  |3+4|
        |  4|  4|  4|
        +---+---+---+
        |1+2|3  |4  |
        |  4|  4|  4|
        +---+---+---+

        +---+---+---+
        |1+2|2+3|2+3|
        |  3|  4|  3|
        +---+---+---+
        |1  |2  |3  |
        |  3|  3|  3|
        +---+---+---+

It might be useful to augment these with top-half (CTRL) and
bottom-half (SHIFT) variants.

other functions
---------------

The right function cluster has room for:

  * non-full-screen maximize
  * application windows
  * mission control
  * prev/next desktop (PG UP, PG DN)
  * screenshot (PRNT SCRN)

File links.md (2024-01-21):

keycaps
-------

interest checks and group buys

  * https://www.mechgroupbuys.com/keycaps
  * https://keycaplendar.firebaseapp.com/
  * https://keycapsets.com/

switches
--------

  * Cherry MX clear
      * https://www.cherrymx.de/en/cherry-mx/mx-special/mx-clear.html
      * https://github.com/keyboardio/keyswitch_documentation/blob/master/datasheets/Cherry/EN_CHERRY_MX1A-Cxxx.pdf

  * Cherry MX dimensions
      * https://github.com/keyboardio/keyswitch_documentation/blob/master/datasheets/Cherry/mx_series.pdf
      * https://media.digikey.com/pdf/Data%20Sheets/Cherry%20PDFs/MX%20Series.pdf

  * Kailh MX hotswap socket
      * https://github.com/keyboardio/keyswitch_documentation/blob/master/datasheets/Kailh/PG151101S11-MX-Socket.pdf

inspiration
-----------

  * displaced arrow cluster
      - https://geekhack.org/index.php?topic=121633.0

  * drone vibration isolation mount
      - https://geekhack.org/index.php?topic=119899.0

  * XT TKL FRL with grommet mount
      - https://geekhack.org/index.php?topic=121658.0

  * upper case curved like keycap profile
      - https://geekhack.org/index.php?topic=117922.0
      - https://en.wikipedia.org/wiki/Apple_Extended_Keyboard

  * rounded front and rear
      - https://vortexgear.store/products/pc-66-68-key
      - https://clickykeyboards.com/wp-content/uploads/2016/11/030.jpg

  * rounded sides
      - https://clickclack.io/pages/pixelspace-capsule

  * "chicong", curved case rounded front and rear
      - https://deskthority.net/wiki/Chicony_KB-5160
      - https://deskthority.net/wiki/Chicony_KB-5161

  * XT with angled function row

      - https://geekhack.org/index.php?topic=117595.0

plastics
--------

1.5mm

  * natural whiteish acetal POM-C - £48

    https://www.plasticstockist.com/Acetal-Sheet/Natural-Acetal-Sheet.aspx

  * black polypropylene - £9

    https://www.plasticstockist.com/Polypropylene-Sheet/Black-Polypropylene-Co-Polymer-Sheet.aspx

  * clear polycarbonate - £26

    https://www.plasticstockist.com/Polycarbonate-Sheet/Palsun-Polycarbonate-Sheet-With-Uv-Protection-On-One-Side.aspx

3mm

  * midnight black frost S2 9221 - £42

    https://www.plasticstockist.com/Black-Frost-Perspex-Sheet/Midnight-Black-9221-Frost-Perspex-Cast-Acrylic-Sheet.aspx

  * slate grey frost 15% xmit S2 9T23 - £42

    https://www.plasticstockist.com/Grey-Frost-Perspex-Sheet/Slate-Grey-9t23-Frost-Perspex-Cast-Acrylic-Sheet.aspx

  * matte black secret sign 16% xmit SA 9T25 - £39

    https://www.plasticstockist.com/Secret-Sign-Perspex-Sheet/Black-White-Secret-Sign-Perspex-with-16-Light-Transmission.aspx

  * mineral grey S2 9643 - £57

    https://www.plasticstockist.com/Naturals-Perspex-Sheet/Mineral-Grey-Naturals-Perspex-Acrylic-Sheet.aspx

  * platinum 10% xmit pearlescent 9PY2 - £72

    https://www.plasticstockist.com/Pearlescent-acrylic/Platinum-9py2-Perspex-Pearlescent-Acrylic-Sheet.aspx

  * ash grey S2 9642 - £57

    https://www.plasticstockist.com/Naturals-Perspex-Sheet/Ash-Grey-Naturals-Perspex-Acrylic-Sheet.aspx

  * pearl 20% xmit pearlescent 1PY1 - £72

    https://www.plasticstockist.com/Pearlescent-acrylic/Pearl-1py1-Perspex-Pearlescent-Acrylic-Sheet.aspx

  * white 25% xmit opal 028 - £28

    https://www.plasticstockist.com/Opal-White-Perspex-Sheet/Opal-028-Cast-Perspex-Acrylic-Sheet-With-26-Percent-Light-Transmission.aspx

  * white silk 44% xmit opal 040 - £35

    https://www.plasticstockist.com/Silk-Acrylic-Sheet/Opal-040-Silk-Perspex-Acrylic-Sheet-With-One-Side-Anti-Reflective-51-Percent-Light-Transmission.aspx

accent colours

  * red 433 - £35

    https://www.plasticstockist.com/Red-Perspex-Sheet/Red-433-Cast-Perspex-Acrylic-Sheet.aspx

  * red 4TL2 5% xmit - £50

    https://www.plasticstockist.com/LED-Optimised-Perspex-Sheet/Red-4TL2-Perspex-Spectrum-LED-Acrylic-Sheet.aspx

  * azure blue frost 32% xmit S2 7T1F - £42

    https://www.plasticstockist.com/Blue-Frost-Perspex-Sheet/Azure-Blue-7t1f-Frost-Perspex-Cast-Acrylic-Sheet.aspx

  * turquoise blue 7748 - £35

    https://www.plasticstockist.com/Blue-Perspex-Sheet/Blue-7748-Turquoise-Cast-Perspex-Acrylic-Sheet.aspx

  * aurora violet frost 36% xmit S2 7T58 - £42

    https://www.plasticstockist.com/Purple-Frost-Perspex-Sheet/Aurora-Violet-7t58-Frost-Perspex-Acrylic-Sheet-With-55-Percent-Light-Transmission.aspx

  * purple 4% xmit violet 886 - £35

    https://www.plasticstockist.com/Purple-Perspex-Sheet/Violet-886-Cast-Perspex-Acrylic-Sheet.aspx

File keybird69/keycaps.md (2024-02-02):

notes on keycap sets for unix 69
================================

I would like a Dolch style keycap set, preferably sculpted,
spherical top, with icon modifiers.

sculpted
--------

With sculpted keycaps, the right column works well as all R1
(e.g. F1...F4) because that makes it easier to feel where
delete / return / up are. (Tho might not work so well with a
high profile mountainous F row, such as SA or MT3.)

dyesub
------

The nightfox keycaps are black on dark grey; it turns out I
rely too much on looking at the keys, so dark low contrast is
unhelpful.

This makes the SP DSA PBT dyesub keycaps less attractive,
though perhaps it would work to use the alphas from SP DSA
Dolch with SP DSA PBT dyesub icon modifiers. Sadly I can't
pull this trick with SP DSS.

----------------------------------------------------------------

Notes on some specific options...

Whitefox / Nightfox
-------------------

https://kono.store/products/whitefox-keycap-set

Cherry profile sublimated PBT

base set covers everything

(limited options for right column)

Matt3o MTNU Susu
----------------

https://prototypist.net/products/group-buy-gmk-mtnu-susu-keycap-set

medium profile sculpted spherical double shot PBT

base set covers everything £95

Sadly the MTNU group buy ended before I learned some facts
that make it more tempting :-(

keycaps:

Light warm gray: RAL classic 7022

Dark warm gray: RAL classic 7021

Red: RAL classic 3020

legends:

Cream / Wax yellow: RAL design 090-90-30

Chlorophyll green: RAL design 110-70-70

Clear blue: RAL design 240-60-40

Matt3o MT3 Susuwatari
---------------------

https://drop.com/buy/drop-matt3o-mt3-susuwatari-custom-keycap-set

high profile sculpted spherical double shot ABS

extra height F row

base set covers everything $99

the extras are nice, $49
  * red arrows
  * R2 up arrow
  * fun function column options

PBTfans Dolch
-------------

https://kbdfans.com/collections/pbtfans-in-stock/products/pbtfans-dolch

Cherry profile double shot ABS

base set covers everything, $80

(tab legend is cluttered)

WASD DIY
--------

https://www.wasdkeyboards.com/104-key-custom-cherry-mx-keycap-set.html

OEM profile ABS UV-coated $65

KAT
---

medium height spherical profile, squareish tops

sculpted without steps, extra height keys on F row

dyesub PBT

### refined

https://mekibo.com/products/kat-refined

$118 + $55 shipping

### cyberspace

https://mykeyboard.eu/catalogue/kat-cyberspace-alpha_2449/

glow-in-the-dark!

€109, but won't ship to uk unless I spend more!

### iron

https://mykeyboard.eu/catalogue/kat-iron-alpha_2387/

€100 with rusty modifiers <3 and alternate profile up key

SP DSS dolch
------------

https://pimpmykeyboard.com/sp-dss-dolch-keyset-two-shot/

medium height spherical sculpted profile

  * ABS colours
      - GE (light)
      - GX (dark)
      - RA (red)

  * alpha kit $82
      - F1 - F4 (light)
      - `~ (light + dark)
      - \| (light)
      - space (light 6.25u)
      - ??? esc (dark)

  * modifier kit $36
      - tab (1.5u)
      - left shift (2.25u)
      - left fn (1.25u)
      - left alt (1.25u)
      - left super (1.25u)
      - ??? return (dark 2.25u)
      - ??? arrows (dark)

  * pro modifier kit $27
      - left ctrl (1.75u)
      - right shift (1.75u)
      - right super (1u)
      - right ctrl (1u)
      - right alt (1u)
      - right fn (1u)
      - backspace (1.5u)

  * ??? red kit $7
      - esc
      - return
      - arrows

extreme mod kit has 1.5u del, but R1 not R2 :-(

alphas + mods + pro + red + del = $157

SP DSA standard keysets
-----------------------

https://pimpmykeyboard.com/sp-dsa-standard-keysets-sublimated/

  * PBT colours
      - GSF (dark)
      - GQT (pale)
      - RBH (red)
      - http://www.keyboard-layout-editor.com/#/gists/74c60d38ef1efecc72a03eb15da15d9a

  * dark low contrast

  * alpha kit $60
      - `~ (pale)
      - space (6.25u)

  * 60% icon modifier kit $22
      - tab (1.5u)
      - return (2.25u)
      - left shift (2.25u)
      - left menu (1.25u)
      - left alt (1.25u)
      - left super (1.25u)
      - ??? esc (dark)

  * 40% icon modifier kit $32
      - right super (1u)
      - right menu (1u)
      - right fn1 fn2 fn3 pn (1u)
      - right shift (1.75u)
      - ??? right alt (1u)

  * arrow kit $5 (red? pale?)

  * individual keys $5 each
      - esc (1u red icon A1)
      - left ctrl (1.75u dark icon A7)
      - right ctrl (1u dark icon A7)
      - delete (1.5u dark icon A2)
      - \| (1u pale)

total $142

SP DSA Dolch key sets
---------------------

https://pimpmykeyboard.com/sp-dsa-dolch-keyset-two-shot/

  * ABS colours
      - GE (pale)
      - GX (dark)
      - RA (red)
      - http://www.keyboard-layout-editor.com/#/gists/2848ea7a272aa571d140694ff6bbe04c

  * alpha kit $60
      - `~ (pale)
      - space (6.25u)

  * 60% modifier kit $20
      - `~ (dark)
      - tab (1.5u)
      - left shift (2.25u)
      - return (2.25u)
      - left win (1.25u x2)
      - left alt (1.25u x2)
      - left menu (1.25u x2)

  * alternate kit $29
      - left fn (1.25u)
      - control (1.75u)
      - backspace (1.5u)
      - right shift (1.75u)
      - right fn (1u x2)
      - right win (1u)
      - right menu (1u)

  * red kit $7
      - esc
      - arrows
      - return

  * tkl adder kit $30 [nope]
      - esc (dark)
      - f1 - f4 (pale)
      - f5 - f8 (dark)
      - arrows (dark)

  * ISO kit $12 [nope]
      - \| (1u pale)

  * missing
      - alt (1u)
      - ctrl (1u)
      - replacements for win

  * individual keys $5 each
      - \| (1u pale)
      - f1 - f4 (iu pale)

total $158 or $141

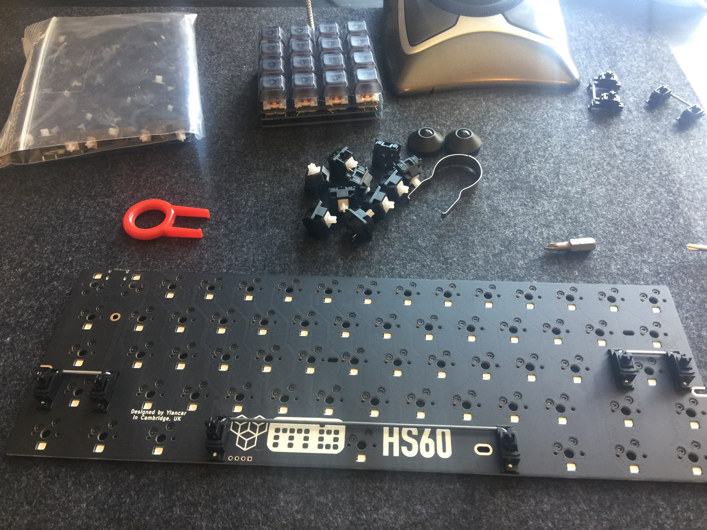
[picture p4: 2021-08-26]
hhkbeeb/photos/2021-07-29-hs60-a-stabs.jpg

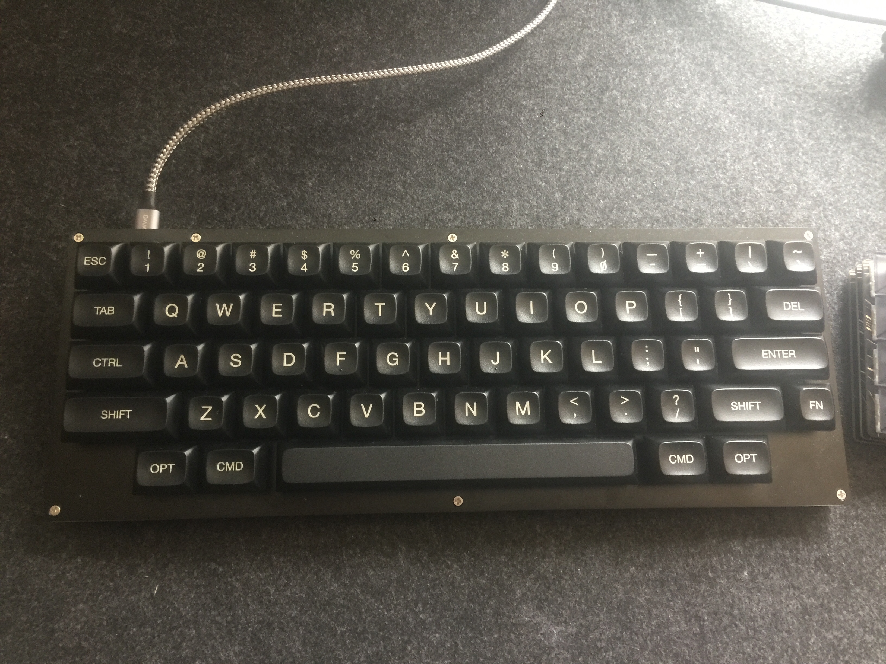
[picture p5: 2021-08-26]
hhkbeeb/photos/2021-08-20-screws-silver.jpg

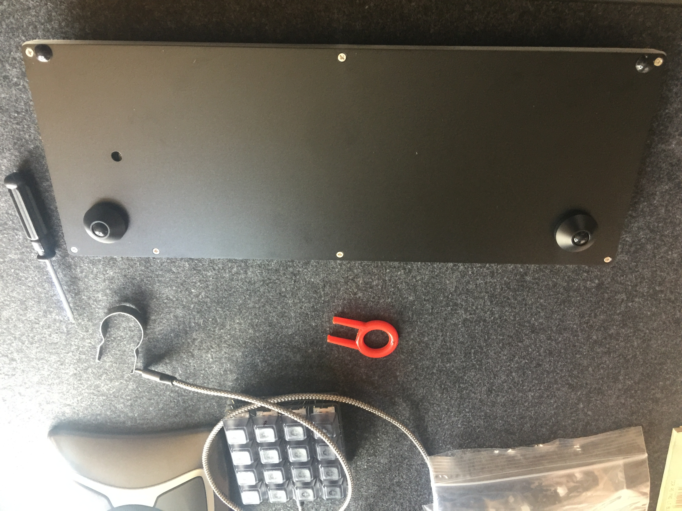
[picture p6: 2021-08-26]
hhkbeeb/photos/2021-07-29-hs60-h-base.jpg

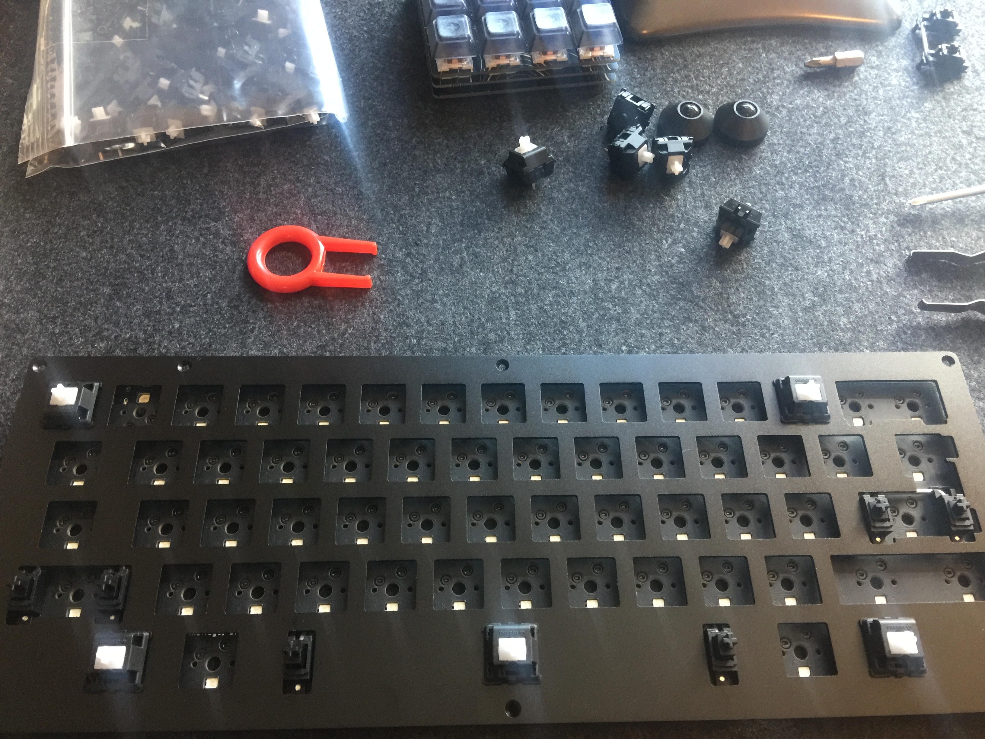
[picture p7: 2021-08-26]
hhkbeeb/photos/2021-07-29-hs60-c-plate.jpg

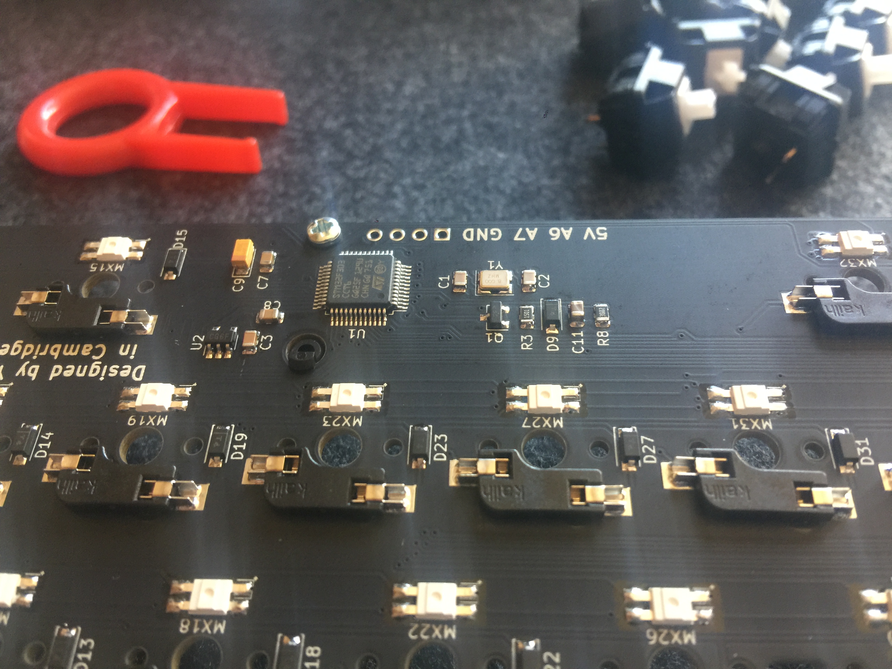
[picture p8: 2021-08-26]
hhkbeeb/photos/2021-07-29-hs60-b-careful.jpg

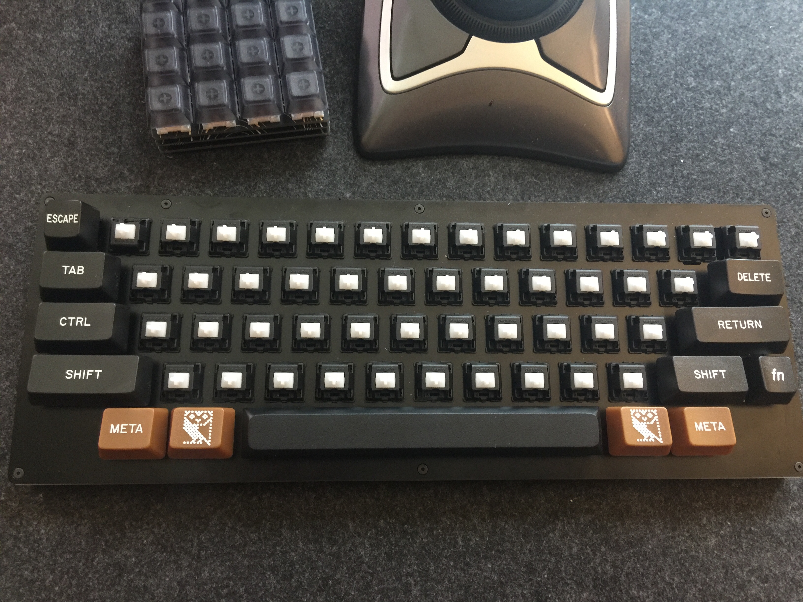
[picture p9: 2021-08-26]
hhkbeeb/photos/2021-08-26-c-mod-caps.jpg

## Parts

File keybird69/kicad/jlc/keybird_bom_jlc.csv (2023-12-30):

Comment | Designator | Footprint | LCSC Part Number
1N4148 diode | D32,D80,D36,D10,D54,D64,D22,D71,D16,D11,D27,D26,D34,D84,D76,D65,D70,D15,D13,D01,D42,D24,D07,D45,D57,D20,D44,D74,D56,D61,D14,D21,D00,D23,D77,D62,D47,D06,D35,D31,D82,D04,D87,D30,D40,D43,D12,D41,D17,D33,D25,D63,D60,D02,D67,D03,D50,D51,D52,D83,D73,D53,D72,D86,D66,D85,D55,D81,D05 | D_SOD-123 | C81598

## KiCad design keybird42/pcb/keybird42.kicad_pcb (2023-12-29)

Board: 2 copper layers, 174 parts (1 on the bottom side), 107 nets.

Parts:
D111, D112, D113, D114, D115, D116, D117, D121, D122, D123, D124, D125, D126, D127, D131, D132, D133, D134, D135, D136, D137, D211, D212, D213, D214, D215, D216, D217, D221, D222, D223, D225, D226, D227, D231, D232, D233, D234, D235, D236, D237, D311, D312, D314, D315, D316, D317, D321, D322, D323, D324, D325, D327, D331, D332, D333, D334, D335, D336, D337, D411, D412, D413, D414, D415, D416, D417, D421, D423, D424, D425, D426, D427, D431, D432, D433, D434, D436, D437, D501, D502, D503, D504, D505, D506, D507: 1N4148W; D_SOD-123_HandSolder_Back
J1: IObird FPC; Hirose_FH12-40S-0.5SH_1x40-1MP_P0.50mm_Horizontal
SW111, SW112, SW113, SW114, SW115, SW116, SW117, SW121, SW122, SW123, SW124, SW125, SW126, SW127, SW131, SW132, SW133, SW134, SW135, SW136, SW137, SW211, SW212, SW213, SW214, SW215, SW216, SW217, SW221, SW222, SW223, SW225, SW226, SW227, SW231, SW232, SW233, SW234, SW235, SW236, SW237, SW311, SW312, SW314, SW315, SW316, SW317, SW321, SW322, SW323, SW324, SW325, SW327, SW331, SW332, SW333, SW334, SW335, SW336, SW337, SW411, SW412, SW413, SW414, SW415, SW416, SW417, SW421, SW423, SW424, SW425, SW426, SW427, SW431, SW432, SW433, SW434, SW436, SW437, SW501, SW502, SW503, SW504, SW505, SW506, SW507: SW_MX; SW_Hotswap_Kailh_MX
U1: RP2040-Tiny

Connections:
/COL1: J1.9 (GPIO4), SW111.1, SW121.1, SW131.1, SW211.1, SW221.1, SW231.1, SW311.1, SW321.1, SW331.1, SW411.1, SW421.1, SW431.1, SW501.1, U1.15 (GPIO15)
/COL2: J1.21 (GPIO14), SW112.1, SW122.1, SW132.1, SW212.1, SW222.1, SW232.1, SW312.1, SW322.1, SW332.1, SW412.1, SW432.1, SW502.1, U1.7 (GPIO7)
/COL3: J1.27 (GPIO19), SW113.1, SW123.1, SW133.1, SW213.1, SW223.1, SW233.1, SW323.1, SW333.1, SW413.1, SW423.1, SW433.1, SW503.1, U1.12 (GPIO12)
/COL4: J1.15 (GPIO9), SW114.1, SW124.1, SW134.1, SW214.1, SW234.1, SW314.1, SW324.1, SW334.1, SW414.1, SW424.1, SW434.1, SW504.1, U1.13 (GPIO13)
/COL5: J1.26 (GPIO18), SW115.1, SW125.1, SW135.1, SW215.1, SW225.1, SW235.1, SW315.1, SW325.1, SW335.1, SW415.1, SW425.1, SW505.1, U1.11 (GPIO11)
/COL6: J1.20 (GPIO13), SW116.1, SW126.1, SW136.1, SW216.1, SW226.1, SW236.1, SW316.1, SW336.1, SW416.1, SW426.1, SW436.1, SW506.1, U1.6 (GPIO6)
/COL7: J1.8 (GPIO3), SW117.1, SW127.1, SW137.1, SW217.1, SW227.1, SW237.1, SW317.1, SW327.1, SW337.1, SW417.1, SW427.1, SW437.1, SW507.1, U1.16 (GPIO26)
/ROW11: D111.1 (K), D112.1 (K), D113.1 (K), D114.1 (K), D115.1 (K), D116.1 (K), D117.1 (K), J1.7 (GPIO2), U1.17 (GPIO27)
/ROW12: D121.1 (K), D122.1 (K), D123.1 (K), D124.1 (K), D125.1 (K), D126.1 (K), D127.1 (K), J1.6 (GPIO1), U1.18 (GPIO28)
/ROW13: D131.1 (K), D132.1 (K), D133.1 (K), D134.1 (K), D135.1 (K), D136.1 (K), D137.1 (K), J1.5 (GPIO0), U1.19 (GPIO29)
/ROW21: D211.1 (K), D212.1 (K), D213.1 (K), D214.1 (K), D215.1 (K), D216.1 (K), D217.1 (K), J1.19 (GPIO12), U1.5 (GPIO5)
/ROW22: D221.1 (K), D222.1 (K), D223.1 (K), D225.1 (K), D226.1 (K), D227.1 (K), J1.18 (GPIO11), U1.4 (GPIO4)
/ROW23: D231.1 (K), D232.1 (K), D233.1 (K), D234.1 (K), D235.1 (K), D236.1 (K), D237.1 (K), J1.17 (GPIO10), U1.3 (GPIO3)
/ROW31: D311.1 (K), D312.1 (K), D314.1 (K), D315.1 (K), D316.1 (K), D317.1 (K), J1.25 (GPIO17), U1.10 (GPIO10)
/ROW32: D321.1 (K), D322.1 (K), D323.1 (K), D324.1 (K), D325.1 (K), D327.1 (K), J1.24 (GPIO16), U1.9 (GPIO9)
/ROW33: D331.1 (K), D332.1 (K), D333.1 (K), D334.1 (K), D335.1 (K), D336.1 (K), D337.1 (K), J1.23 (GPIO15), U1.8 (GPIO8)
/ROW41: D411.1 (K), D412.1 (K), D413.1 (K), D414.1 (K), D415.1 (K), D416.1 (K), D417.1 (K), J1.14 (GPIO8), U1.2 (GPIO2)
/ROW42: D421.1 (K), D423.1 (K), D424.1 (K), D425.1 (K), D426.1 (K), D427.1 (K), J1.13 (GPIO7), U1.1
/ROW43: D431.1 (K), D432.1 (K), D433.1 (K), D434.1 (K), D436.1 (K), D437.1 (K), J1.12 (GPIO6), U1.0 (GPIO0)
/ROW50: D501.1 (K), D502.1 (K), D503.1 (K), D504.1 (K), D505.1 (K), D506.1 (K), D507.1 (K), J1.11 (GPIO5), U1.14 (GPIO14)
GND: J1.4 (GND), J1.10 (GND), J1.16 (GND), J1.22 (GND), J1.28 (GND), J1.34 (GND), J1.40 (GND), U1.21 (GND)
unnamed: D111.2 (A), SW111.2
unnamed: D112.2 (A), SW112.2
unnamed: D113.2 (A), SW113.2
unnamed: D114.2 (A), SW114.2
unnamed: D115.2 (A), SW115.2
unnamed: D116.2 (A), SW116.2
unnamed: D117.2 (A), SW117.2
unnamed: D121.2 (A), SW121.2
unnamed: D122.2 (A), SW122.2
unnamed: D123.2 (A), SW123.2
unnamed: D124.2 (A), SW124.2
unnamed: D125.2 (A), SW125.2
unnamed: D126.2 (A), SW126.2
unnamed: D127.2 (A), SW127.2
unnamed: D131.2 (A), SW131.2
unnamed: D132.2 (A), SW132.2
unnamed: D133.2 (A), SW133.2
unnamed: D134.2 (A), SW134.2
unnamed: D135.2 (A), SW135.2
unnamed: D136.2 (A), SW136.2
unnamed: D137.2 (A), SW137.2
unnamed: D211.2 (A), SW211.2
unnamed: D212.2 (A), SW212.2
unnamed: D213.2 (A), SW213.2
unnamed: D214.2 (A), SW214.2
unnamed: D215.2 (A), SW215.2
unnamed: D216.2 (A), SW216.2
unnamed: D217.2 (A), SW217.2
unnamed: D221.2 (A), SW221.2
unnamed: D222.2 (A), SW222.2
unnamed: D223.2 (A), SW223.2
unnamed: D225.2 (A), SW225.2
unnamed: D226.2 (A), SW226.2
unnamed: D227.2 (A), SW227.2
unnamed: D231.2 (A), SW231.2
unnamed: D232.2 (A), SW232.2
unnamed: D233.2 (A), SW233.2
unnamed: D234.2 (A), SW234.2
unnamed: D235.2 (A), SW235.2
unnamed: D236.2 (A), SW236.2
unnamed: D237.2 (A), SW237.2
unnamed: D311.2 (A), SW311.2
unnamed: D312.2 (A), SW312.2
unnamed: D314.2 (A), SW314.2
unnamed: D315.2 (A), SW315.2
unnamed: D316.2 (A), SW316.2
unnamed: D317.2 (A), SW317.2
unnamed: D321.2 (A), SW321.2
unnamed: D322.2 (A), SW322.2
unnamed: D323.2 (A), SW323.2
unnamed: D324.2 (A), SW324.2
unnamed: D325.2 (A), SW325.2
unnamed: D327.2 (A), SW327.2
unnamed: D331.2 (A), SW331.2
unnamed: D332.2 (A), SW332.2
unnamed: D333.2 (A), SW333.2
unnamed: D334.2 (A), SW334.2
unnamed: D335.2 (A), SW335.2
unnamed: D336.2 (A), SW336.2
unnamed: D337.2 (A), SW337.2
unnamed: D411.2 (A), SW411.2
unnamed: D412.2 (A), SW412.2
unnamed: D413.2 (A), SW413.2
unnamed: D414.2 (A), SW414.2
unnamed: D415.2 (A), SW415.2
unnamed: D416.2 (A), SW416.2
unnamed: D417.2 (A), SW417.2
unnamed: D421.2 (A), SW421.2
unnamed: D423.2 (A), SW423.2
unnamed: D424.2 (A), SW424.2
unnamed: D425.2 (A), SW425.2
unnamed: D426.2 (A), SW426.2
unnamed: D427.2 (A), SW427.2
unnamed: D431.2 (A), SW431.2
unnamed: D432.2 (A), SW432.2
unnamed: D433.2 (A), SW433.2
unnamed: D434.2 (A), SW434.2
unnamed: D436.2 (A), SW436.2
unnamed: D437.2 (A), SW437.2
unnamed: D501.2 (A), SW501.2
unnamed: D502.2 (A), SW502.2
unnamed: D503.2 (A), SW503.2
unnamed: D504.2 (A), SW504.2
unnamed: D505.2 (A), SW505.2
unnamed: D506.2 (A), SW506.2
unnamed: D507.2 (A), SW507.2

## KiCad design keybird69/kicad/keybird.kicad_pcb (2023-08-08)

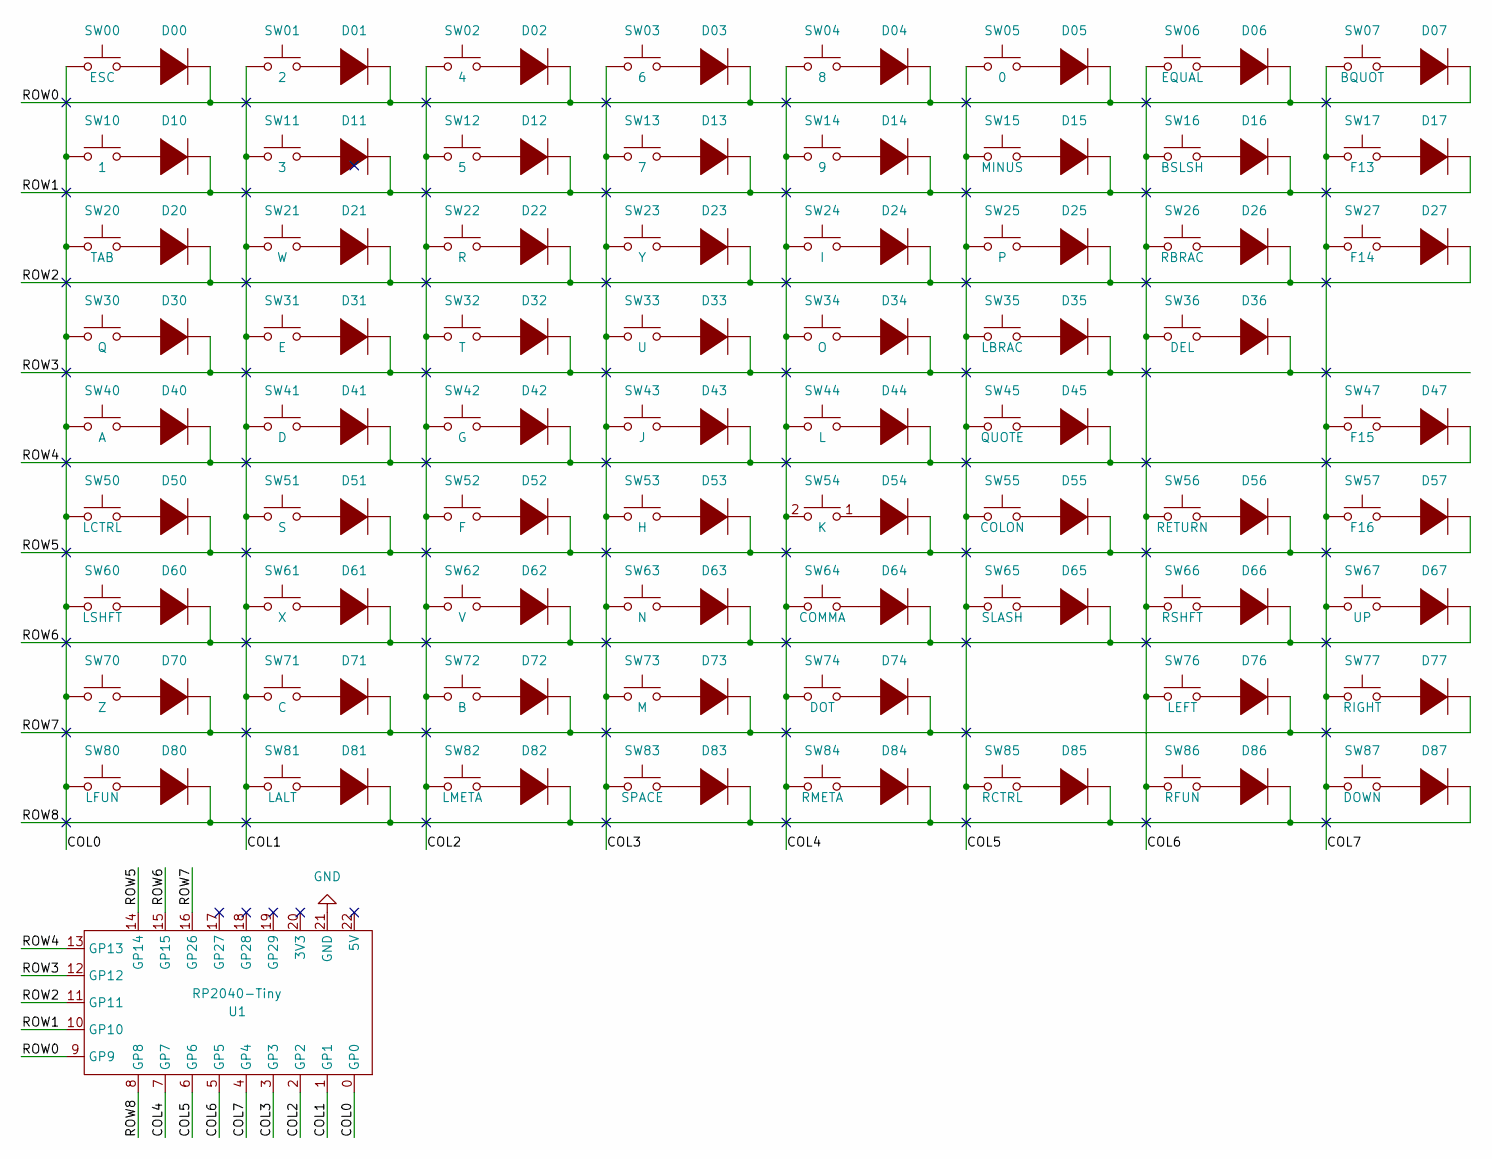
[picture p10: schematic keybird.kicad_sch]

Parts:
D00, D01, D02, D03, D04, D05, D06, D07, D10, D11, D12, D13, D14, D15, D16, D17, D20, D21, D22, D23, D24, D25, D26, D27, D30, D31, D32, D33, D34, D35, D36, D40, D41, D42, D43, D44, D45, D47, D50, D51, D52, D53, D54, D55, D56, D57, D60, D61, D62, D63, D64, D65, D66, D67, D70, D71, D72, D73, D74, D76, D77, D80, D81, D82, D83, D84, D85, D86, D87: DIODE; D_SOD-123
SW00: ESC; SW_Hotswap_Kailh_MX_1.00u
SW01: 2; SW_Hotswap_Kailh_MX_1.00u
SW02: 4; SW_Hotswap_Kailh_MX_1.00u
SW03: 6; SW_Hotswap_Kailh_MX_1.00u
SW04: 8; SW_Hotswap_Kailh_MX_1.00u
SW05: 0; SW_Hotswap_Kailh_MX_1.00u
SW06: EQUAL; SW_Hotswap_Kailh_MX_1.00u
SW07: BQUOT; SW_Hotswap_Kailh_MX_1.00u
SW10: 1; SW_Hotswap_Kailh_MX_1.00u
SW11: 3; SW_Hotswap_Kailh_MX_1.00u
SW12: 5; SW_Hotswap_Kailh_MX_1.00u
SW13: 7; SW_Hotswap_Kailh_MX_1.00u
SW14: 9; SW_Hotswap_Kailh_MX_1.00u
SW15: MINUS; SW_Hotswap_Kailh_MX_1.00u
SW16: BSLSH; SW_Hotswap_Kailh_MX_1.00u
SW17: F13; SW_Hotswap_Kailh_MX_1.00u
SW20: TAB; SW_Hotswap_Kailh_MX_1.50u
SW21: W; SW_Hotswap_Kailh_MX_1.00u
SW22: R; SW_Hotswap_Kailh_MX_1.00u
SW23: Y; SW_Hotswap_Kailh_MX_1.00u
SW24: I; SW_Hotswap_Kailh_MX_1.00u
SW25: P; SW_Hotswap_Kailh_MX_1.00u
SW26: RBRAC; SW_Hotswap_Kailh_MX_1.00u
SW27: F14; SW_Hotswap_Kailh_MX_1.00u
SW30: Q; SW_Hotswap_Kailh_MX_1.00u
SW31: E; SW_Hotswap_Kailh_MX_1.00u
SW32: T; SW_Hotswap_Kailh_MX_1.00u
SW33: U; SW_Hotswap_Kailh_MX_1.00u
SW34: O; SW_Hotswap_Kailh_MX_1.00u
SW35: LBRAC; SW_Hotswap_Kailh_MX_1.00u
SW36: DEL; SW_Hotswap_Kailh_MX_1.50u
SW40: A; SW_Hotswap_Kailh_MX_1.00u
SW41: D; SW_Hotswap_Kailh_MX_1.00u
SW42: G; SW_Hotswap_Kailh_MX_1.00u
SW43: J; SW_Hotswap_Kailh_MX_1.00u
SW44: L; SW_Hotswap_Kailh_MX_1.00u
SW45: QUOTE; SW_Hotswap_Kailh_MX_1.00u
SW47: F15; SW_Hotswap_Kailh_MX_1.00u
SW50: LCTRL; SW_Hotswap_Kailh_MX_1.75u
SW51: S; SW_Hotswap_Kailh_MX_1.00u
SW52: F; SW_Hotswap_Kailh_MX_1.00u
SW53: H; SW_Hotswap_Kailh_MX_1.00u
SW54: K; SW_Hotswap_Kailh_MX_1.00u
SW55: COLON; SW_Hotswap_Kailh_MX_1.00u
SW56: RETURN; SW_Hotswap_Kailh_MX_2.25u
SW57: F16; SW_Hotswap_Kailh_MX_1.00u
SW60: LSHFT; SW_Hotswap_Kailh_MX_2.25u
SW61: X; SW_Hotswap_Kailh_MX_1.00u
SW62: V; SW_Hotswap_Kailh_MX_1.00u
SW63: N; SW_Hotswap_Kailh_MX_1.00u
SW64: COMMA; SW_Hotswap_Kailh_MX_1.00u
SW65: SLASH; SW_Hotswap_Kailh_MX_1.00u
SW66: RSHFT; SW_Hotswap_Kailh_MX_1.75u
SW67: UP; SW_Hotswap_Kailh_MX_1.00u
SW70: Z; SW_Hotswap_Kailh_MX_1.00u
SW71: C; SW_Hotswap_Kailh_MX_1.00u
SW72: B; SW_Hotswap_Kailh_MX_1.00u
SW73: M; SW_Hotswap_Kailh_MX_1.00u
SW74: DOT; SW_Hotswap_Kailh_MX_1.00u
SW76: LEFT; SW_Hotswap_Kailh_MX_1.00u
SW77: RIGHT; SW_Hotswap_Kailh_MX_1.00u
SW80: LFUN; SW_Hotswap_Kailh_MX_1.25u
SW81: LALT; SW_Hotswap_Kailh_MX_1.25u
SW82: LMETA; SW_Hotswap_Kailh_MX_1.25u
SW83: SPACE; SW_Hotswap_Kailh_MX_6.25u
SW84: RMETA; SW_Hotswap_Kailh_MX_1.00u
SW85: RCTRL; SW_Hotswap_Kailh_MX_1.00u
SW86: RFUN; SW_Hotswap_Kailh_MX_1.00u
SW87: DOWN; SW_Hotswap_Kailh_MX_1.00u
U1: RP2040-Tiny

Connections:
/COL0: SW00.2, SW10.2, SW20.2, SW30.2, SW40.2, SW50.2, SW60.2, SW70.2, SW80.2, U1.0 (GP0)
/COL1: SW01.2, SW11.2, SW21.2, SW31.2, SW41.2, SW51.2, SW61.2, SW71.2, SW81.2, U1.1 (GP1)
/COL2: SW02.2, SW12.2, SW22.2, SW32.2, SW42.2, SW52.2, SW62.2, SW72.2, SW82.2, U1.2 (GP2)
/COL3: SW03.2, SW13.2, SW23.2, SW33.2, SW43.2, SW53.2, SW63.2, SW73.2, SW83.2, U1.3 (GP3)
/COL4: SW04.2, SW14.2, SW24.2, SW34.2, SW44.2, SW54.2, SW64.2, SW74.2, SW84.2, U1.7 (GP7)
/COL5: SW05.2, SW15.2, SW25.2, SW35.2, SW45.2, SW55.2, SW65.2, SW85.2, U1.6 (GP6)
/COL6: SW06.2, SW16.2, SW26.2, SW36.2, SW56.2, SW66.2, SW76.2, SW86.2, U1.5 (GP5)
/COL7: SW07.2, SW17.2, SW27.2, SW47.2, SW57.2, SW67.2, SW77.2, SW87.2, U1.4 (GP4)
/ROW0: D00.2 (A), D01.2 (A), D02.2 (A), D03.2 (A), D04.2 (A), D05.2 (A), D06.2 (A), D07.2 (A), U1.9 (GP9)
/ROW1: D10.2 (A), D11.2 (A), D12.2 (A), D13.2 (A), D14.2 (A), D15.2 (A), D16.2 (A), D17.2 (A), U1.10 (GP10)
/ROW2: D20.2 (A), D21.2 (A), D22.2 (A), D23.2 (A), D24.2 (A), D25.2 (A), D26.2 (A), D27.2 (A), U1.11 (GP11)
/ROW3: D30.2 (A), D31.2 (A), D32.2 (A), D33.2 (A), D34.2 (A), D35.2 (A), D36.2 (A), U1.12 (GP12)
/ROW4: D40.2 (A), D41.2 (A), D42.2 (A), D43.2 (A), D44.2 (A), D45.2 (A), D47.2 (A), U1.13 (GP13)
/ROW5: D50.2 (A), D51.2 (A), D52.2 (A), D53.2 (A), D54.2 (A), D55.2 (A), D56.2 (A), D57.2 (A), U1.14 (GP14)
/ROW6: D60.2 (A), D61.2 (A), D62.2 (A), D63.2 (A), D64.2 (A), D65.2 (A), D66.2 (A), D67.2 (A), U1.15 (GP15)
/ROW7: D70.2 (A), D71.2 (A), D72.2 (A), D73.2 (A), D74.2 (A), D76.2 (A), D77.2 (A), U1.16 (GP26)
/ROW8: D80.2 (A), D81.2 (A), D82.2 (A), D83.2 (A), D84.2 (A), D85.2 (A), D86.2 (A), D87.2 (A), U1.8 (GP8)
GND: U1.21 (GND)
unnamed: D00.1 (K), SW00.1
unnamed: D01.1 (K), SW01.1
unnamed: D02.1 (K), SW02.1
unnamed: D03.1 (K), SW03.1
unnamed: D04.1 (K), SW04.1
unnamed: D05.1 (K), SW05.1
unnamed: D06.1 (K), SW06.1
unnamed: D07.1 (K), SW07.1
unnamed: D10.1 (K), SW10.1
unnamed: D11.1 (K), SW11.1
unnamed: D12.1 (K), SW12.1
unnamed: D13.1 (K), SW13.1
unnamed: D14.1 (K), SW14.1
unnamed: D15.1 (K), SW15.1
unnamed: D16.1 (K), SW16.1
unnamed: D17.1 (K), SW17.1
unnamed: D20.1 (K), SW20.1
unnamed: D21.1 (K), SW21.1
unnamed: D22.1 (K), SW22.1
unnamed: D23.1 (K), SW23.1
unnamed: D24.1 (K), SW24.1
unnamed: D25.1 (K), SW25.1
unnamed: D26.1 (K), SW26.1
unnamed: D27.1 (K), SW27.1
unnamed: D30.1 (K), SW30.1
unnamed: D31.1 (K), SW31.1
unnamed: D32.1 (K), SW32.1
unnamed: D33.1 (K), SW33.1
unnamed: D34.1 (K), SW34.1
unnamed: D35.1 (K), SW35.1
unnamed: D36.1 (K), SW36.1
unnamed: D40.1 (K), SW40.1
unnamed: D41.1 (K), SW41.1
unnamed: D42.1 (K), SW42.1
unnamed: D43.1 (K), SW43.1
unnamed: D44.1 (K), SW44.1
unnamed: D45.1 (K), SW45.1
unnamed: D47.1 (K), SW47.1
unnamed: D50.1 (K), SW50.1
unnamed: D51.1 (K), SW51.1
unnamed: D52.1 (K), SW52.1
unnamed: D53.1 (K), SW53.1
unnamed: D54.1 (K), SW54.1
unnamed: D55.1 (K), SW55.1
unnamed: D56.1 (K), SW56.1
unnamed: D57.1 (K), SW57.1
unnamed: D60.1 (K), SW60.1
unnamed: D61.1 (K), SW61.1
unnamed: D62.1 (K), SW62.1
unnamed: D63.1 (K), SW63.1
unnamed: D64.1 (K), SW64.1
unnamed: D65.1 (K), SW65.1
unnamed: D66.1 (K), SW66.1
unnamed: D67.1 (K), SW67.1
unnamed: D70.1 (K), SW70.1
unnamed: D71.1 (K), SW71.1
unnamed: D72.1 (K), SW72.1
unnamed: D73.1 (K), SW73.1
unnamed: D74.1 (K), SW74.1
unnamed: D76.1 (K), SW76.1
unnamed: D77.1 (K), SW77.1
unnamed: D80.1 (K), SW80.1
unnamed: D81.1 (K), SW81.1
unnamed: D82.1 (K), SW82.1
unnamed: D83.1 (K), SW83.1
unnamed: D84.1 (K), SW84.1
unnamed: D85.1 (K), SW85.1
unnamed: D86.1 (K), SW86.1
unnamed: D87.1 (K), SW87.1

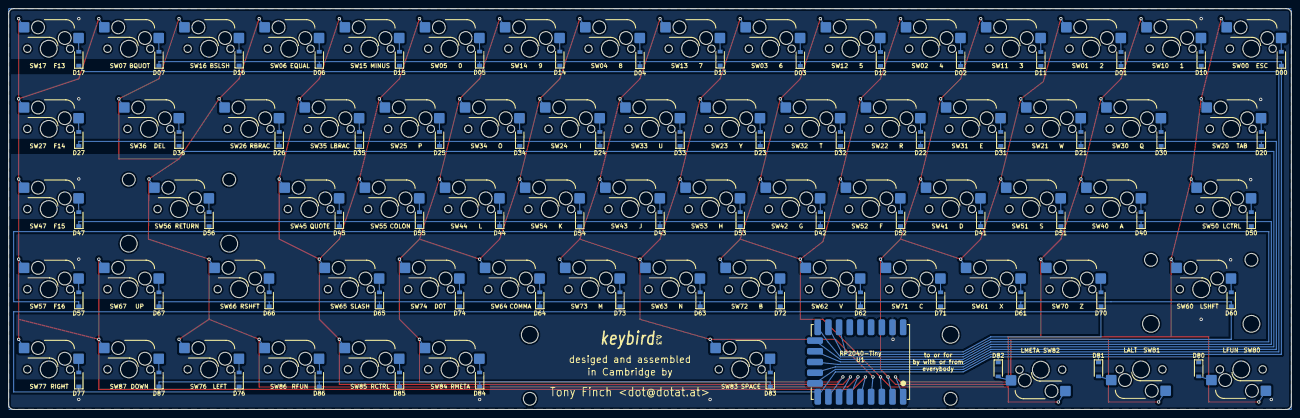
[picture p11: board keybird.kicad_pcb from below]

Board: 2 copper layers, 304.8 x 95.2 mm, 142 parts (70 on the bottom side), 86 nets.

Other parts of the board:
ST_ENTER: Stabilizer_Cherry_MX_2.00u
ST_SHIFT: Stabilizer_Cherry_MX_2.00u
ST_SPACE: Stabilizer_Cherry_MX_6.25u

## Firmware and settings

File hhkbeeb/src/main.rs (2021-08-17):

#![allow(dead_code)]

use anyhow::*;

const WIDTH: i8 = 15;
const DEPTH: i8 = 5;

const HHKB: bool = WIDTH > 10;

const fn hhkb_ortho(hhkb: f64, ortho: f64) -> f64 {
    if HHKB {
        hhkb
    } else {
        ortho
    }
}

// we are mostly working in inches, except for the holes
const MM_IN: f64 = 25.4;

const KERF: f64 = 0.01; // inch

const SWU: f64 = 0.75; // inch

// standrad corner radii, based on layer thicknesses
const SMOOTH: f64 = 1.0 / 8.0; // like 3mm acrylic
const BLUNT: f64 = SMOOTH / 2.0; // like PCB or plate
const SHARP: f64 = BLUNT / 2.0;

const KEYS_X: f64 = 0.0;
const KEYS_Y: f64 = 0.0;
const KEYS_W: f64 = WIDTH as f64 * SWU;
const KEYS_D: f64 = DEPTH as f64 * SWU;

const BLACK_LR: f64 = 1.0 * SWU;
const BLACK_NF: f64 = 0.5 * SWU;
const BLACK_X: f64 = -BLACK_LR;
const BLACK_Y: f64 = -BLACK_NF;
const BLACK_W: f64 = KEYS_W + BLACK_LR * 2.0;
const BLACK_D: f64 = KEYS_D + BLACK_NF * 2.0;

const CREAM_LR: f64 = 1.0 * SWU;
const CREAM_NEAR: f64 = 0.75 * SWU;
const CREAM_FAR: f64 = 1.25 * SWU;
const CREAM_X: f64 = BLACK_X - CREAM_LR;
const CREAM_Y: f64 = BLACK_Y - CREAM_FAR;
const CREAM_W: f64 = BLACK_W + CREAM_LR * 2.0;
const CREAM_D: f64 = BLACK_D + CREAM_FAR + CREAM_NEAR;

const BOX_GAP: f64 = BLUNT;
const BOX_X: f64 = -BOX_GAP;
const BOX_Y: f64 = -BOX_GAP;
const BOX_W: f64 = KEYS_W + BOX_GAP * 2.0;
const BOX_D: f64 = KEYS_D + BOX_GAP * 2.0;

const RECESS_LEFT: f64 = CREAM_LR + BLACK_LR + hhkb_ortho(SWU / 8.0, SWU / 2.0);
const RECESS_MID: f64 = hhkb_ortho(SWU * 14.0 / 8.0, SWU * 3.0);
const RECESS_RIGHT: f64 = CREAM_W - RECESS_LEFT - RECESS_MID;
const RECESS_INNER: f64 = CREAM_LR + BLACK_LR - BOX_GAP;
const RECESS_L_IN: f64 = RECESS_LEFT - RECESS_INNER;
const RECESS_R_IN: f64 = RECESS_RIGHT - RECESS_INNER;
const RECESS_PCB: f64 = CREAM_FAR + BLACK_NF;
const RECESS_BOX: f64 = RECESS_PCB - BOX_GAP;

// use the kerf to provide the right fit
const SCREW_HOLE: f64 = 3.0 / MM_IN;
const RIVET_HOLE: f64 = 5.0 / MM_IN;

const AROUND_HOLE: f64 = 4.0 / MM_IN; // radius

const DRILL_LEFT: f64 = BLACK_X + AROUND_HOLE;
const DRILL_RIGHT: f64 = BLACK_X + BLACK_W - AROUND_HOLE;
const DRILL_LEFTISH: f64 = KEYS_X + KEYS_W * 1.0 / 3.0;
const DRILL_RIGHTISH: f64 = KEYS_X + KEYS_W * 2.0 / 3.0;
const DRILL_FAR: f64 = BLACK_Y + AROUND_HOLE;
const DRILL_NEAR: f64 = BLACK_Y + BLACK_D - AROUND_HOLE;

// for switches the kerf is larger than the tolerance
const SWITCH_HOLE: f64 = 14.0 / MM_IN - KERF;

// base of keycap is 18mm, stab hole is 15.5mm
const STAB_DEPTH: f64 = (0.26 - 0.484 + 0.53) * 2.0;
const STAB_WIDTH: f64 = 1.0 / 3.0;
const STAB_OFFSET_2U: f64 = 1.0 / 2.0;
const STAB_OFFSET_7U: f64 = 4.5 / 2.0;

const STAB_GAP: f64 = STAB_OFFSET_2U - STAB_WIDTH / 2.0 - SWITCH_HOLE / 2.0;
const STAB_JOIN: f64 = SWITCH_HOLE * 0.75;

fn base() -> Path {
    Path::begin(CREAM_X, CREAM_Y)
        .frame(CREAM_W, CREAM_D, SMOOTH)
        .left(RECESS_RIGHT)
        .ws(BLUNT)
        .ucw(RECESS_PCB, RECESS_MID, RECESS_PCB, BLUNT)
        .ws(BLUNT)
        .left(RECESS_LEFT)
        .close()
        .drill(RIVET_HOLE, RIVET_HOLE)
}

fn socket() -> Path {
    Path::begin(CREAM_X, CREAM_Y)
        .frame(CREAM_W, CREAM_D, SMOOTH)
        .uws(RECESS_RIGHT, RECESS_BOX, RECESS_R_IN, BLUNT)
        .frame(BOX_W, BOX_D, BLUNT)
        .uws(RECESS_L_IN, RECESS_BOX, RECESS_LEFT, BLUNT)
        .close()
        .drill(RIVET_HOLE, RIVET_HOLE)
}

fn closed() -> Path {
    Path::begin(CREAM_X, CREAM_Y)
        .rect(CREAM_W, CREAM_D, SMOOTH)
        .goto(BOX_X, BOX_Y)
        .rect(BOX_W, BOX_D, BLUNT)
        .drill(SCREW_HOLE, RIVET_HOLE)
}

fn plate() -> Path {
    Path::begin(CREAM_X, CREAM_Y)
        .rect(CREAM_W, CREAM_D, SMOOTH)
        .drill(SCREW_HOLE, SCREW_HOLE)
        .keys()
}

fn shim() -> Path {
    Path::begin(CREAM_X, CREAM_Y)
        .rect(CREAM_W, CREAM_D, SMOOTH)
        .goto(KEYS_X, KEYS_Y)
        .rect(KEYS_W, KEYS_D, SHARP)
        .drill(SCREW_HOLE, SCREW_HOLE)
        .feet()
}

fn cream_top() -> Path {
    // inner radius should be sharper than outer radius of black top
    Path::begin(CREAM_X, CREAM_Y)
        .rect(CREAM_W, CREAM_D, SMOOTH)
        .goto(BLACK_X, BLACK_Y)
        .rect(BLACK_W, BLACK_D, SHARP)
}

fn black_top() -> Path {
    // base of keycaps is 18mm leaving a 0.5mm gap between keycaps and
    // the KEYS rectangle; the SHARP radius is 0.8mm; distance between
    // keycap corner and centre of SHARP curve is 0.3mm orthogonally,
    // or sqrt(2) * 0.3 == 0.4mm diagonally, so distance betweem
    // keycap corner and SHARP corner is 0.4mm.
    Path::begin(BLACK_X, BLACK_Y)
        .rect(BLACK_W, BLACK_D, BLUNT)
        .goto(KEYS_X, KEYS_Y)
        .rect(KEYS_W, KEYS_D, SHARP)
        .drill(SCREW_HOLE, SCREW_HOLE)
}

fn main() -> Result<()> {
    let mut all = Path { cuts: vec![] };
    std::env::set_current_dir(if HHKB { "hhkb" } else { "keybow" })?;
    all.concat(save_svg("L0_clear15.svg", base())?);
    all.concat(save_svg("L12_beige30.svg", socket())?);
    all.concat(save_svg("L3_beige30.svg", closed())?);
    all.concat(save_svg("L4_clear15.svg", plate())?);
    all.concat(save_svg("L5_clear15.svg", shim())?);
    all.concat(save_svg("L67_beige30.svg", beige_top())?);
    all.concat(save_svg("L8_black50.svg", black_top())?);
    save_svg("all.svg", all)?;
    Ok(())
}

impl Path {
    fn drill(mut self, d_far: f64, d_near: f64) -> Path {
        self = self
            .goto(DRILL_LEFT, DRILL_FAR)
            .hole(d_far)
            .goto(DRILL_RIGHT, DRILL_FAR)
            .hole(d_far)
            .goto(DRILL_LEFT, DRILL_NEAR)
            .hole(d_near)
            .goto(DRILL_RIGHT, DRILL_NEAR)
            .hole(d_near);
        if WIDTH > DEPTH * 2 {
            self = self
                .goto(DRILL_LEFTISH, DRILL_FAR)
                .hole(d_far)
                .goto(DRILL_RIGHTISH, DRILL_FAR)
                .hole(d_far)
                .goto(DRILL_LEFTISH, DRILL_NEAR)
                .hole(d_near)
                .goto(DRILL_RIGHTISH, DRILL_NEAR)
                .hole(d_near);
        }
        self
    }

    fn keys(self) -> Path {
        if HHKB {
            self.hhkb_keys()
        } else {
            self.ortho_keys()
        }
    }

    fn feet(self) -> Path {
        if HHKB {
            self.hhkb_feet()
        } else {
            self.ortho_feet()
        }
    }

    fn ortho_keys(mut self) -> Path {
        for x in 0..WIDTH {
            for y in 0..DEPTH {
                self = self.switch(1.0, x as f64, y as f64);
            }
        }
        self
    }

    fn ortho_feet(mut self) -> Path {
        for y in 1..DEPTH {
            self = self.ortho_foot(1.0, y as f64);
            self = self.ortho_foot(3.0, y as f64);
        }
        self
    }

    fn ortho_foot(self, x: f64, y: f64) -> Path {
        self.goto(x * SWU, y * SWU)
            .hole(RIVET_HOLE)
            .goto(x * SWU, y * SWU)
            .hole((AROUND_HOLE + y / MM_IN) * 2.0)
    }

    fn hhkb_keys(mut self) -> Path {
        for x in 0..WIDTH {
            self = self.switch(1.0, x as f64, 0.0);
            if x < WIDTH - 3 {
                self = self.switch(1.0, x as f64 + 1.5, 1.0);
            }
            if x < WIDTH - 4 {
                self = self.switch(1.0, x as f64 + 1.75, 2.0);
            }
            if x < WIDTH - 5 {
                self = self.switch(1.0, x as f64 + 2.25, 3.0);
            }
        }
        self.switch(1.5, 0.0, 1.0)
            .switch(1.5, -1.5, 1.0)
            .switch(1.75, 0.0, 2.0)
            .switch(2.25, -2.25, 2.0)
            .switch(2.25, 0.0, 3.0)
            .switch(1.75, -2.75, 3.0)
            .switch(1.0, -1.0, 3.0)
            .switch(1.5, 0.0, 4.0)
            .switch(1.0, 1.5, 4.0)
            .switch(1.5, 2.5, 4.0)
            .switch(7.0, 4.0, 4.0)
            .switch(1.5, -4.0, 4.0)
            .switch(1.0, -2.5, 4.0)
            .switch(1.5, -1.5, 4.0)
    }

    fn hhkb_feet(mut self) -> Path {
        for y in 1..DEPTH {
            self = self.hhkb_foot(4.0 * SWU, y as f64);
            self = self.hhkb_foot(11.0 * SWU, y as f64);
        }
        self
    }

    fn hhkb_foot(self, mid: f64, y: f64) -> Path {
        let wid = (DRILL_LEFTISH - DRILL_LEFT) / 2.0;
        let rad = AROUND_HOLE + y / MM_IN;
        self.goto(mid - wid, y * SWU)
            .hole(RIVET_HOLE)
            .goto(mid + wid, y * SWU)
            .hole(RIVET_HOLE)
            .goto(mid - wid - rad, y * SWU - rad)
            .rect(wid * 2.0 + rad * 2.0, rad * 2.0, AROUND_HOLE)
    }

    fn switch(self, w: f64, mut x: f64, mut y: f64) -> Path {
        let width = w * SWU;
        let depth = 1.0 * SWU;
        if x < 0.0 {
            x += WIDTH as f64;
        }
        x = x * SWU + width / 2.0;
        y = y * SWU + depth / 2.0;
        if 1.0 - KERF < w && w < 2.0 - KERF {
            return self.goto(x, y).cutout(SWITCH_HOLE, SWITCH_HOLE, KERF);
        }
        if 2.0 - KERF < w && w < 3.0 - KERF {
            return self.switch_stab(x, y);
        }
        if 7.0 - KERF < w && w < 7.0 + KERF {
            return self
                .goto(x - STAB_OFFSET_7U, y)
                .cutout(STAB_WIDTH, STAB_DEPTH, KERF)
                .goto(x + STAB_OFFSET_7U, y)
                .cutout(STAB_WIDTH, STAB_DEPTH, KERF)
                .goto(x, y)
                .cutout(SWITCH_HOLE, SWITCH_HOLE, KERF);
        }
        unreachable!("unsupported key size {}", w)
    }

    fn switch_stab(self, x: f64, y: f64) -> Path {
        self.goto(x - SWITCH_HOLE / 2.0, y - SWITCH_HOLE / 2.0)
            .ws(KERF)
            .ucw(
                (SWITCH_HOLE - STAB_JOIN) / 2.0,
                STAB_GAP,
                (STAB_DEPTH - STAB_JOIN) / 2.0,
                KERF,
            )
            .frame(STAB_WIDTH, STAB_DEPTH, KERF)
            .ucw(
                (STAB_DEPTH - STAB_JOIN) / 2.0,
                STAB_GAP,
                (SWITCH_HOLE - STAB_JOIN) / 2.0,
                KERF,
            )
            .ws(KERF)
            .right(SWITCH_HOLE)
            .ws(KERF)
            .ucw(
                (SWITCH_HOLE - STAB_JOIN) / 2.0,
                STAB_GAP,
                (STAB_DEPTH - STAB_JOIN) / 2.0,
                KERF,
            )
            .frame(STAB_WIDTH, STAB_DEPTH, KERF)
            .ucw(
                (STAB_DEPTH - STAB_JOIN) / 2.0,
                STAB_GAP,
                (SWITCH_HOLE - STAB_JOIN) / 2.0,
                KERF,
            )
            .ws(KERF)
            .left(SWITCH_HOLE)
            .close()
    }
}

#[derive(Clone, Copy, Debug, PartialEq)]
struct Pos {
    x: f64,
    y: f64,
}

const NO_PLACE: Pos = Pos { x: f64::NAN, y: f64::NAN };

#[derive(Clone, Copy, Debug, PartialEq)]
struct Bounds {
    min: Pos,
    max: Pos,
}

fn bounds(bbox: Bounds, pos: Pos) -> Bounds {
    let min = |a, b| if a <= b { a } else { b };
    let max = |a, b| if a >= b { a } else { b };
    Bounds {
        min: Pos { x: min(bbox.min.x, pos.x), y: min(bbox.min.y, pos.y) },
        max: Pos { x: max(bbox.max.x, pos.x), y: max(bbox.max.y, pos.y) },
    }
}

#[derive(Clone, Copy, Debug, PartialEq)]
enum Cut {
    Goto(Pos),
    Back(f64),
    Forth(f64),
    Left(f64),
    Right(f64),
    Corner(f64, u8, f64, f64), // radius, sweep, dx, dy
    Close(),
    Circle(f64), // diameter
}
use Cut::*;

fn save_svg(name: &str, path: Path) -> Result<Path> {
    let bbox = ensure_closed(&path.cuts);
    let margin = 0.25;
    let width = bbox.max.x - bbox.min.x + margin * 2.0;
    let depth = bbox.max.y - bbox.min.y + margin * 2.0;
    let size = (bbox.min.x - margin, bbox.min.y - margin, width, depth);
    let document = svg::Document::new()
        .set("width", format!("{}in", width))
        .set("height", format!("{}in", depth))
        .set("viewBox", size)
        .add(to_svg(&path.cuts));
    svg::save(name, &document)?;
    Ok(path)
}

type SvgCircle = svg::node::element::Circle;
type SvgGroup = svg::node::element::Group;
type SvgPath = svg::node::element::Path;
type PathData = svg::node::element::path::Data;

type SvgStyle<'a> = &'a [(&'a str, svg::node::Value)];

fn to_svg(cuts: &[Cut]) -> SvgGroup {
    let style: SvgStyle = &[
        ("fill", "none".into()),
        ("stroke", "goldenrod".into()),
        ("stroke-width", KERF.into()),
    ];

    let mut g = SvgGroup::new();
    let mut p = PathData::new();
    let mut pr = 0.0;

    let mut it = cuts.iter().peekable();
    while let Some(&this) = it.next() {
        let next = match it.peek() {
            Some(&thing) => *thing,
            None => return g,
        };

        match (this, next) {
            (Goto(Pos { x, y }), Circle(d)) => {
                let mut c = SvgCircle::new()
                    .set("cx", x)
                    .set("cy", y)
                    .set("r", d / 2.0);
                for attr in style {
                    c = c.set(attr.0, attr.1.clone());
                }
                g = g.add(c);
            }
            (Circle(_), _) => (),

            (_, Close()) => {
                let mut path = SvgPath::new().set("d", p.close());
                for attr in style {
                    path = path.set(attr.0, attr.1.clone());
                }
                g = g.add(path);
                p = PathData::new();
            }
            (Close(), _) => (),

            (Goto(Pos { x, y }), Corner(nr, _, _, _)) => {
                p = p.move_to((x + nr, y))
            }

            (Back(depth), Corner(nr, _, _, _)) => {
                p = p.line_by((0, -(depth - pr - nr)))
            }

            (Forth(depth), Corner(nr, _, _, _)) => {
                p = p.line_by((0, depth - pr - nr))
            }

            (Left(depth), Corner(nr, _, _, _)) => {
                p = p.line_by((-(depth - pr - nr), 0))
            }

            (Right(depth), Corner(nr, _, _, _)) => {
                p = p.line_by((depth - pr - nr, 0))
            }

            (Corner(r, sw, dx, dy), _) => {
                p = p.elliptical_arc_by((r, r, 0, 0, sw, dx, dy));
                pr = r;
            }

            _ => unimplemented!(),
        }
    }
    unreachable!()
}

fn ensure_closed(cuts: &[Cut]) -> Bounds {
    let mut start: Option<Pos> = None;
    let mut cur = NO_PLACE;
    let mut bbox = Bounds { min: cur, max: cur };
    for cut in cuts {
        match *cut {
            Close() => {
                let dx = start.unwrap().x - cur.x;
                let dy = start.unwrap().y - cur.y;
                assert!(dx * dx + dy * dy < 0.0001 * 0.0001);
                start = None;
            }
            Goto(pos) => {
                cur = pos;
                start = Some(pos);
            }
            Back(depth) => cur.y -= depth,
            Forth(depth) => cur.y += depth,
            Left(width) => cur.x -= width,
            Right(width) => cur.x += width,
            Corner(_, _, _, _) => (),
            Circle(diameter) => {
                let r = diameter / 2.0;
                bbox = bounds(bbox, Pos { x: cur.x - r, y: cur.y - r });
                bbox = bounds(bbox, Pos { x: cur.x + r, y: cur.y + r });
            }
        }
        bbox = bounds(bbox, cur);
    }
    bbox
}

macro_rules! path_state {
    { $name:ident : $($item:item)* } => {
        #[derive(Clone, Debug, PartialEq)]
        struct $name {
            cuts: Vec<Cut>,
        }
        impl $name {
            $($item)*
        }
    };
}

macro_rules! path_funky {
    { $name:ident($arg:ident) -> $state:ident = $cons:ident $vals:tt } => {
        fn $name(mut self, $arg: f64) -> $state {
            self.cuts.push($cons $vals);
            $state { cuts: self.cuts }
        }
    }
}

macro_rules! path_fn {
    { $name:ident($arg:ident) -> $state:ident = $cons:ident } => {
        path_funky!{ $name($arg) -> $state = $cons($arg) }
    }
}

path_state! {
    Path:

    fn begin(x: f64, y: f64) -> Moved {
        Moved { cuts: vec![Goto(Pos{x, y})] }
    }

    fn goto(mut self, x: f64, y: f64) -> Moved {
        self.cuts.push(Goto(Pos{x,y}));
        Moved { cuts: self.cuts }
    }

    fn concat(&mut self, other: Path) {
        self.cuts.extend_from_slice(&other.cuts);
    }
}

path_state! {
    Moved:

    fn hole(mut self, diameter: f64) -> Path {
        self.cuts.push(Circle(diameter));
        self.cuts.push(Close());
        Path { cuts: self.cuts }
    }

    // first corner must be top left
    path_funky! { ws(radius) -> Forthing = Corner(radius, 0, -radius, radius) }

    // around the outside omitting the back
    fn frame(self, width: f64, depth: f64, radius: f64) -> Lefting {
        self.ws(radius).forth(depth)
            .ws(radius).right(width)
            .ws(radius).back(depth)
            .ws(radius)
    }

    fn rect(self, width: f64, depth: f64, radius: f64) -> Path {
        self.frame(width, depth, radius)
            .left(width)
            .close()
    }

    fn cutout(mut self, width: f64, depth: f64, radius: f64) -> Path {
        match self.cuts.pop() {
            Some(Goto(Pos{ x, y })) => {
                self.cuts.push(Goto(Pos{ x: x - width / 2.0,
                                         y: y - depth / 2.0 }));
                self.rect(width, depth, radius)
            }
            _ => unreachable!(),
        }
    }
}

path_state! {
    Backing:
    path_fn! { back(depth) -> Backed = Back }

    fn ucw(self, back: f64, right: f64, forth: f64, radius: f64) -> Forthed {
        self.back(back).cw(radius)
            .right(right).cw(radius)
            .forth(forth)
    }
}

path_state! {
    Forthing:
    path_fn! { forth(depth) -> Forthed = Forth }

    fn ucw(self, forth: f64, left: f64, back: f64, radius: f64) -> Backed {
        self.forth(forth).cw(radius)
            .left(left).cw(radius)
            .back(back)
    }
}

path_state! {
    Lefting:
    path_fn! { left(width) -> Lefted = Left }

    fn uws(self, left: f64, forth: f64, right: f64, radius: f64) -> Righted {
        self.left(left).ws(radius)
            .forth(forth).ws(radius)
            .right(right)
    }
}
path_state! {
    Righting:
    path_fn! { right(width) -> Righted = Right }

    fn uws(self, right: f64, back: f64, left: f64, radius: f64) -> Lefted {
        self.right(right).ws(radius)
            .back(back).ws(radius)
            .left(left)
    }
}

path_state! {
    Backed:
    path_funky! { cw(radius) -> Righting = Corner(radius, 1, radius, -radius) }
    path_funky! { ws(radius) -> Lefting = Corner(radius, 0, -radius, -radius) }

    fn frame(self, width: f64, depth: f64, radius: f64) -> Backing {
        self.ws(radius).left(width)
            .ws(radius).forth(depth)
            .ws(radius).right(width)
            .ws(radius)
    }
}

path_state! {
    Forthed:
    path_funky! { cw(radius) -> Lefting = Corner(radius, 1, -radius, radius) }
    path_funky! { ws(radius) -> Righting = Corner(radius, 0, radius, radius) }

    fn frame(self, width: f64, depth: f64, radius: f64) -> Forthing {
        self.ws(radius).right(width)
            .ws(radius).back(depth)
            .ws(radius).left(width)
            .ws(radius)
    }
}

path_state! {
    Lefted:
    path_funky! { cw(radius) -> Backing = Corner(radius, 1, -radius, -radius) }
    path_funky! { ws(radius) -> Forthing = Corner(radius, 0, -radius, radius) }

    fn close(mut self) -> Path {
        self.cuts.push(Close());
        ensure_closed(&self.cuts);
        Path { cuts: self.cuts }
    }
}

path_state! {
    Righted:
    path_funky! { cw(radius) -> Forthing = Corner(radius, 1, radius, radius) }
    path_funky! { ws(radius) -> Backing = Corner(radius, 0, radius, -radius) }

    // inner cut, in opposite direction
    fn frame(self, width: f64, depth: f64, radius: f64) -> Righting {
        self.cw(radius).forth(depth)
            .cw(radius).left(width)
            .cw(radius).back(depth)
            .cw(radius)
    }
}

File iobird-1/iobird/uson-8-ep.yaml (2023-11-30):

# definition of a uson-8-ep footprint
# used by the Winbond W25Q16JVUXIQ flash chip
# https://gitlab.com/kicad/libraries/kicad-footprint-generator/-/tree/master/scripts/Packages/Package_NoLead__DFN_QFN_LGA_SON

uson_8_ep:
  device_type: 'USON'
  library: iobird

  custom_name_format: 'USON-8-EP_2x3mm'
  size_source: 'https://datasheet.lcsc.com/lcsc/2205122030_Winbond-Elec-W25Q16JVUXIQ_C2843335.pdf'

  ipc_class: 'qfn'

  num_pins_x: 0
  num_pins_y: 4
  pitch: 0.5

  body_size_x: 3.0 +/-0.1
  body_size_y: 2.0 +/-0.1
  overall_height: 0.55 +/-0.05

  lead_width: 0.25  +/-0.05
  lead_len: 0.45 +/-0.05

  EP_size_x: 0.2 +/-0.05
  EP_size_y: 1.6 +/-0.05

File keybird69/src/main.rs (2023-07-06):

use std::collections::HashSet;

const MM_IN: f64 = 25.4;
const KEY_UNIT: f64 = 0.75 * MM_IN;

const SCREW_HOLE: f64 = 3.0;
const RIVET_HOLE: f64 = 5.0;
const SWITCH_HOLE: f64 = 14.0;


const ROWS: usize = 5;
const WIDTH: usize = 16;
const GROUPS: usize = WIDTH / 2;
const TRACKS: usize = 9;


macro_rules! words {
    { $($word:tt)* } => { vec![ $( stringify!($word), )* ] }
}

struct Key {
    name: &'static str,
    u: f64, // 0.75 in
    x: f64, // 0.75 in
    y: f64, // 0.75 in
    group: usize,
    track: usize,
}

type Keyboard = Vec<Vec<Key>>;

fn expand_keyboard() -> Keyboard {
    let key_names = vec![
        words![ ESC 1 2 3 4 5 6 7 8 9 0 MINUS EQUAL BSLS GRAVE F13 ],
        words![ TAB  Q W E R T Y U I O P        LBRC RBRC BSPC F14 ],
        words![ LCTL  A S D F G H J K L       SCLN QUOTE ENTER F15 ],
        words![ LSFT   Z X C V B N M   COMMA DOT SLASH RSFT UP F16 ],
        words![ LFN LALT LGUI SPACE  RGUI RCTL RFN LEFT DOWN RIGHT ],
    ];

    let key_groups = vec![
        vec![0, 0, 1, 1, 2, 2, 3, 3, 4, 4, 5, 5, 6, 6, 7, 7],
        vec![0, 0, 1, 1, 2, 2, 3, 3, 4, 4, 5, 5, 6, 6, 7],
        vec![0, 0, 1, 1, 2, 2, 3, 3, 4, 4, 5, 5, 6, 7],
        vec![0, 0, 1, 1, 2, 2, 3, 3, 4, 4, 5, 6, 7, 7],
        vec![0, 1, 2, 3, 4, 5, 6, 6, 7, 7],
    ];

    let key_tracks = vec![
        vec![0, 1, 0, 1, 0, 1, 0, 1, 0, 1, 0, 1, 0, 1, 0, 1],
        vec![2, 3, 2, 3, 2, 3, 2, 3, 2, 3, 2, 3, 2, 3, 2],
        vec![5, 4, 5, 4, 5, 4, 5, 4, 5, 4, 5, 4, 5, 4],
        vec![6, 7, 6, 7, 6, 7, 6, 7, 6, 7, 6, 6, 6, 5],
        vec![8, 8, 8, 8, 8, 8, 8, 7, 8, 7],
    ];

    // consistent number of rows
    assert!(key_names.len() == ROWS);
    assert!(key_groups.len() == ROWS);
    assert!(key_tracks.len() == ROWS);

    let mut kb: Vec<Vec<Key>> = vec![];
    let mut matrix = [[false; TRACKS]; GROUPS];
    let mut name_set = HashSet::new();

    for row in 0..ROWS {
        kb.push(vec![]);
        let len = key_names[row].len();

        // correct length of rows
        assert!(key_groups[row].len() <= WIDTH);

        // consistent length of rows
        assert!(key_groups[row].len() == len);
        assert!(key_tracks[row].len() == len);

        let mut x = 0.0;
        let y = row as f64;

        for k in 0..len {
            let name = key_names[row][k];
            let group = key_groups[row][k];
            let track = key_tracks[row][k];

            // unique names
            assert!(!name_set.contains(name));
            name_set.insert(name);

            // valid group and track numbers
            assert!(group < GROUPS);
            assert!(track < TRACKS);

            // unique matrix positions
            let pos = &mut matrix[group][track];
            assert!(!*pos);
            *pos = true;

            let u = match key_names[row][k] {
                "SPACE" => 6.25,
                "LSFT" | "ENTER" => 2.25,
                "LCTL" | "RSFT" => 1.75,
                "TAB" | "BSPC" => 1.5,
                "LFN" | "LALT" | "LGUI" => 1.25,
                _ => 1.0,
            };

            kb[row].push(Key { name, group, track, x, y, u });

            x += u;
        }
    }

    kb
}

fn print_kle(kb: &Keyboard) {
    let mut rowsep = "";
    for row in 0..ROWS {
        print!("{rowsep}[");
        let mut keysep = "";
        for key in &kb[row] {
            let u = key.u;
            let name = key.name;
            let track = key.track;
            let group = key.group;
            print!(
                "{keysep}\
                {{w:{u}}},\"{track},{group}\
                \\n\\n\\n\\n\\n\\n\\n\\n\\n\
                {name}\""
            );
            keysep = ",";
        }
        print!("]");
        rowsep = ",\n";
    }
    print!("\n");
}

fn print_qmk_matrix() {
    print!(r#"
    "diode_direction": "COL2ROW",
    "matrix_pins": {{
"#);
    print!(r#"        "cols":"#);
    let mut sep = " [";
    for col in 0 ..= 3 {
        print!("{sep}\"GP{col}\"");
        sep = ", ";
    }
    for col in 4 ..= 7 {
        let pin = 11 - col;
        print!("{sep}\"GP{pin}\"");
    }
    println!("],");
    print!(r#"        "rows":"#);
    let mut sep = " [";
    for row in 0 ..= 6 {
        print!("{sep}\"GP{row}\"");
        sep = ", ";
    }
    println!(r#", "GP26", "GP8"]"#);
    println!("    }},");
}

fn print_qmk_layout(kb: &Keyboard) {
    let mut keysep = "[\n";
    print!(r#"
    "layouts": {{
        "LAYOUT_unix69": {{
            "layout": "#);
    for row in 0..ROWS {
        for key in &kb[row] {
            let u = key.u;
            let x = key.x;
            let y = key.y;
            let name = key.name;
            let track = key.track;
            let group = key.group;
            print!("{keysep}                {{ \
                    \"label\": \"{name}\", \
                    \"matrix\": [{track},{group}], \
                    \"x\": {x}, \
                    \"y\": {y}, \
                    \"w\": {u} \
                    }}");
            keysep = ",\n";
        }
    }
    print!("\n            ]\n        }}\n   }}\n");
}

fn print_qmk_keymap(kb: &Keyboard) {
    print!(r#"
// SPDX-License-Identifier: 0BSD OR MIT-0

#include QMK_KEYBOARD_H

// clang-format off

const uint16_t PROGMEM keymaps[][MATRIX_ROWS][MATRIX_COLS] = {{
    [0] = LAYOUT_unix69"#);

    let mut rowsep = "(\n";
    for row in 0..ROWS {
        print!("{rowsep}        ");
        let mut keysep = "";
        for key in &kb[row] {
            match key.name {
                "LFN" | "RFN" => print!("{keysep}MO(1)"),
                name => print!("{keysep}KC_{name}"),
            };
            keysep = ", ";
        }
        rowsep = ",\n";
    }
    print!("),\n}};\n");
}

fn main() {
    let kb = expand_keyboard();
    //print_kle(&kb);
    print_qmk_matrix();
    print_qmk_layout(&kb);
    print_qmk_keymap(&kb);
}

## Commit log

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2021-07-25 add USB plugs to sandwich sketch
    I have given the 5mm design a thicker base plate so that the plug
    doesn't protrude below. But with the feet and what not, maybe this
    isn't necessary.
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2023-06-29 preen annotations and centre rp2040
    [keybird.kicad_sch]
2023-06-29 use net labels instead of long wires
    [keybird.kicad_sch]
2023-06-29 use a proper symbol for the RP20540
    [keybird.kicad_sch]
2023-06-29 much work on the pcb
    [keybird.kicad_pcb, keybird.kicad_sch]
2023-06-30 much pcb fettling
    silkscreen key names from schematic
    diode placement wrt switch connections
    [keybird.kicad_pcb, keybird.kicad_sch]
2023-06-30 pcb edge and cutout for reset buttons
    [keybird.kicad_pcb]
2023-06-30 connecting tracks to diodes
    [keybird.kicad_pcb]
2023-06-30 redo the row lines on the front of the board
    much nicer!
    [keybird.kicad_pcb, keybird.kicad_sch]
2023-06-30 done? no drc errors!
    [keybird.kicad_pcb, keybird.kicad_sch]
2023-07-01 final version with rows on front
    gonna start again, this time better
    [keybird.kicad_pcb]
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2023-07-02 very nice, i think
    [keybird.kicad_pcb, keybird.kicad_sch]
2023-07-02 add ground planes
    with stripes!
    [keybird.kicad_pcb]
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2023-07-03 mounting holes for feet
    [ltbs-base.kicad_pcb, ltbs-top.kicad_pcb]
2023-07-04 redesigning enclosure to make USB adapter fit
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2023-07-04 rectangular case did not work; many different stabilizer dimensions
2023-07-04 add stab cutouts to 2.25 u keys
    [ltbs-top.kicad_pcb]
2023-07-05 slightly adjust keyswitch cutout grid wrt the pcb outline
    [ltbs-top.kicad_pcb]
2023-07-05 remove usb cutout from pcb
    i lack the effort for a bigger revision
    [keybird.kicad_pcb]
2023-07-05 add tooling holes for pcb assembly
    [keybird.kicad_pcb]
2023-07-06 don't need the tooling holes for jlcpcb's cheap mode
    [keybird.kicad_pcb]
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2023-07-06 print keymap.c and fix matrix_pins
    [main.rs]
2023-07-12 extra clearance for stab wires
    [keybird.kicad_pcb]
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2023-07-27 reverse 2u stabs to make room for matrix traces
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2023-07-28 tighten up slightly
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2023-08-08 move edited library footprints into the project
    [keybird.kicad_pcb, keybird.kicad_sch]
2023-08-08 change directory name to match project name
    [keybird.kicad_pcb, keybird.kicad_sch, ltbs-base.kicad_pcb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]
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2023-09-14 DSA keycap model
    from https://grabcad.com/library/dsa-keycap-for-cherry-mx-switches-1
    [dsa.step]
2023-09-14 Cherry MX switch model
    from https://grabcad.com/library/cherry-mx-switch-2
    [mx.step]
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2023-10-27 better beam box, needs adjustment for clearance around pcb
2023-10-27 adjust beam box for clearance around pcb
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2023-10-30 clean up remnants of keybird74
    [dsa.step, mx.step]
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2023-11-30 starting a small rp2040 board
    [iobird.kicad_pcb, iobird.kicad_sch]
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2023-12-01 add xtal to schematic
    [iobird.kicad_sch]
2023-12-01 filling in more parts
    [iobird.kicad_sch]
2023-12-08 more progress
    add decoupling capacitors; name them after the pins they are near
    add FPC socket and hook up the GPIO pins; the power and ground pins of
    the socket match the Raspberry Pi 40 pin HAT header
    the 3v3 pin in the middle of the header is notionally the ADC_AVDD
    and the GPIO_ADC pins are adjacent
    dunno if this will survive board layout
    [iobird.kicad_sch]
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2023-12-09 adafruit-style bootsel instead of pimoroni-style
    [iobird.kicad_sch]
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2023-12-12 start pcb design with switch matrix
    using a 3-way folded matrix, because 7 * 3 == 21 which is the number
    of keys in the top row, and there are 7 keys in the bottom row
    we need three row wires for each row of keys, except the bottom row,
    so 13 rows in all
    13 + 7 == 20 which is the number of pins on an RP2040-Tiny
    [keybird42.kicad_pcb, keybird42.kicad_sch]
2023-12-12 add rp2040-tiny, fix subdir name
    [keybird42.kicad_pcb, keybird42.kicad_sch]
2023-12-12 update switch and diode symbols; ERC passes; refs are a mess
    [keybird42.kicad_sch]
2023-12-12 better row labels
    two digits for row and sub-column
    when these are used in switch and diode references, kicad is less
    confused by pure digits
    [keybird42.kicad_sch]
2023-12-12 use an evil perl script to fix the switch and diode references
    [keybird42.kicad_sch]
2023-12-12 start placing switches on the pcb
    first two rows roughly in place, not properly aligned yet
    [keybird42.kicad_pcb, keybird42.kicad_sch]
2023-12-12 row 3, two more gaps
    [keybird42.kicad_pcb, keybird42.kicad_sch]
2023-12-12 rough positioning of row 4, two more holes
    [keybird42.kicad_pcb, keybird42.kicad_sch]
2023-12-12 row 5, no holes, positioning is very sketchy
    [keybird42.kicad_pcb]
2023-12-12 diodes in roughly the right places
    [keybird42.kicad_pcb]
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2023-12-12 ugh, wanted to move the diodesto the back, not flip them
    [keybird42.kicad_pcb, keybird42.kicad_sch]
2023-12-12 swap pins of switches so that traces to diodes are neater
    [keybird42.kicad_pcb, keybird42.kicad_sch]
2023-12-12 move diodes to back and flip them
    done by editing the libraries
    [keybird42.kicad_pcb, keybird42.kicad_sch]
2023-12-12 hook up per-switch diodes / traces / vias
    and make sure they are in correct relative position
    absolute positions are still wrong
    [keybird42.kicad_pcb]
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2023-12-13 better checks for pcb clearance
2023-12-13 add a footprint for the RP2040-Tiny
    [keybird42.kicad_pcb, keybird42.kicad_sch]
2023-12-14 diode reorg
    swap pins of switches so diodes are wired to upper pads of sockets
    change diodes to sod-123 because that's the commonly available kind
    need to redo traces and vias
    [keybird42.kicad_pcb, keybird42.kicad_sch]
2023-12-14 fix diode placement
    [keybird42.kicad_pcb]
2023-12-14 switches in the right places now, i think
    [keybird42.kicad_pcb]
2023-12-14 align diodes to 750/32 mil grid
    [keybird42.kicad_pcb]
2023-12-14 fix silkscreen text on back
    [keybird42.kicad_pcb]
2023-12-14 mirror switch row numbers
    should make a nicer pattern of vias
    [keybird42.kicad_pcb]
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2023-12-14 making a grid of vias from the RP2040
    [keybird42.kicad_pcb]
2023-12-17 moving the diodes to make more space for the tracks
    [keybird42.kicad_pcb]
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2023-12-17 starting to fix DRC complaints
    [keybird42.kicad_pcb]
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2023-12-18 fix DRC errors
    [keybird42.kicad_pcb, keybird42.kicad_sch]
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2023-12-18 ok now let's hook up the rp2040-tiny again
    [keybird42.kicad_pcb]
2023-12-18 getting there, still need to do ground planes
    [keybird42.kicad_pcb]
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2023-12-29 reduce min hole-hole clearance
    use jlcpcb's via-via clearance instead of their pad-pad clearance
    kicad is applying the constraint to non-plated holes which don't need
    to be restricted in this way. this is enough to suppress the DRC
    complaints.
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2023-12-29 getting there, could do with a tweak i think
    [keybird42.kicad_pcb]
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2023-12-29 starting to break buses to avoid stray track ends
    [keybird42.kicad_pcb]
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2023-12-29 rows 3 broken
    [keybird42.kicad_pcb]
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2023-12-29 adding ground fills
    this will need some additional cunning
    [keybird42.kicad_pcb]
2023-12-30 nearly done?
    do i want to move the buses down a notch for clearance?
    [keybird42.kicad_sch]
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2024-01-03 keep the PCB outline outside the area covered by the keycaps
    this is because
    * above the plate, there must be clearance between the keycaps
    and the sides of the enclosure
    * below the plate, there must be clearance between the PCB
    and the sides of the enclosure
    * for simplicity I would like the sides of the enclosure
    to have the same outline above and below the plate
    * the fasteners are thicker below the plate than above,
    so it might make sense for the enclosure to have thicker
    sides below, but it's tricky to make that work
    * below the plate we also need to allow clearance for the PCB,
    which is tightest around the space bar stabilizer housings
    * so th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
2024-01-03 1mm clearance around the bottom of the PCB
    on reflection, seems better to make space here
    than the sides of the enclosure
2024-01-06 tighten up the board outline around the front
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2024-01-14 increase clearance for usb daughterboard, and more plate holes
2024-01-15 more clearance between buses and switch post holes
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2024-01-15 include keycap outlines and stabilizers in switch footprints
    so far only updated the schematic, pcb next
    [keybird42.kicad_sch]
2024-01-15 update pcb with keycap outlines and built-in stabilizers
    eliminates DRC warnings about stab footprints lacking schematic symbols
    [keybird42.kicad_sch]
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2024-01-16 correct stab orientation; remove sound holes
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2024-01-19 compatibility with short screws
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2024-01-19 add missing stab screws
2024-01-21 update links
    another red accent colour
    fix silk white link
    add another funky keeb design
    hover tkl no longer has horizontal screws
2024-01-23 update ffc pinout
    I tried adding LEDs but in the end decided I didn't really want to
    deal with them
    but for LED support / compatibility I need to dedicate an ffc line
    for LED serial data, because it will be 5V instead of 3.3
    the ffc also needs a line for the bootsel / user button, which will
    be GPIO0 because that is the closest GPIO pin to the QSPI_CS pin
    (assuming there's enough space for the passives...)
    [keybird42.kicad_sch]
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2024-01-24 fix pcba orientation
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2024-01-24 more bending
    the plate sides are too short for laserboost so i need a rethink...
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2024-01-31 correct stab widths; more detailed pcb cutouts
2024-01-31 fix pcba construction for the stacled case
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2024-01-31 remove short screw compat; more keycap clearance; draw one layer at a time
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2024-02-02 fix slow mode with all the switch plate and pcb cutouts
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2024-03-15 increase clearance between laser cut parts
    some fixes where the layout was not parameterized correctly
    make keycaps optional
    remove one foot layer so they still fit - max typing angle is 7.6
    degrees which is ok, don't think i need the option of 9.1 degrees
